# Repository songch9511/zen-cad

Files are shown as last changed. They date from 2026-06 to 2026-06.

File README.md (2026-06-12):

# Zen CAD

기계 설계 에이전트를 위한 assembly-first CAD contract runtime입니다.






Zen CAD는 Codex 같은 범용 에이전트가 자연어 기계 설계 요청을 더 검사 가능한 CAD 작업으로 바꾸도록 돕습니다. 핵심 규칙은 단순합니다. **형상을 예쁘게 만들기 전에 기계적 의도를 먼저 잠급니다.**

워크플로는 CAD-native spec에서 시작합니다. 그 다음 frame, datum, axis, bore, shaft, bolt pattern, pitch reference, clearance, motion relationship, source evidence를 layout, generation, review, handoff artifact 전체에 걸쳐 보존합니다.

## 현재 버전

- 제품/plugin 버전: `1.1.0`
- contract schema 버전: `0.8.0`
- 기본 local generation target: `build123d`
- review target: generated STEP + 선택적 repo-local viewer link/snapshot
- evidence 우선순위: 측정 가능한 geometry check 먼저, visual review는 그 다음, prose caveat는 마지막

## 하는 일

- 자연어 기계 설계 요청을 CAD-native spec으로 변환합니다.
- layout, interface, inspection, proceed review, handoff용 machine-readable contract package를 만듭니다.
- local dependency가 있으면 first-pass build123d STEP artifact를 생성합니다.
- hole, bore, repeated hole pattern, chamfer, 지원되는 fillet approximation, simplified gear teeth 같은 feature intent를 보존합니다.
- 명시적 evidence가 있으면 source-locked STEP/STP 부품을 generated build123d source에 import합니다.
- `interface_frame`과 `replacement_plan` contract로 source/detail CAD가 proxy를 치환해도 locked facts가 움직이지 않게 합니다.
- `detail_shape_plan`으로 custom part가 사용자 shape intent를 따르면서 protected interface zone을 보존하게 합니다.
- repo-local viewer review link와 선택적 PNG snapshot을 package합니다.
- floating body, interference, clearance, fastening, alignment, mesh/contact, implausible support path를 visual/engineering review에서 점검하도록 안내합니다.

## 하지 않는 일

- CAD kernel, CAE solver, manufacturing review, certification process를 대체하지 않습니다.
- supplier SKU 정확성, 재고, rating, certification, compliance claim을 보장하지 않습니다.
- 광범위한 catalog crawling을 기본 동작으로 하지 않습니다.
- screenshot이나 viewer link만으로 완료를 증명하지 않습니다.
- 특정 subagent runtime을 강제하지 않습니다. subagent가 있으면 dispatch plan을 쓰고, 없으면 lead agent가 같은 review role을 순차 실행합니다.

## Workflow

1. locked parameter, frame, interface, inspection target을 포함한 CAD-native spec을 작성합니다.
2. kernel-neutral layout proxy를 생성하고 locked facts가 보존됐는지 검사합니다.
3. build123d source를 export하고 source-level carry-through를 검사합니다.
4. `build123d`가 가능하면 STEP artifact를 생성합니다.
5. standard/catalog proxy는 interface frame mapping과 inspection이 가능할 때 source-locked STEP/STP로 치환합니다.
6. source component가 아닌 custom part는 locked facts와 user shape intent를 기반으로 constrained detail CAD를 생성합니다.
7. inspection report, generated artifact, 선택적 viewer evidence를 proceed gate로 package합니다.
8. visual/mechanical review를 수행하고 가장 작은 source-level 원인을 수정한 뒤 재생성합니다.
9. 사용자 approval 이후 downstream detail handoff를 생성합니다.

## Codex 사용법

local plugin bundle은 [`plugins/zen-cad`](plugins/zen-cad)에 있습니다. 폴더를 project로 연결하는 것만으로는 slash skill이 등록되지 않습니다. `.codex-plugin/marketplace.json`에서 local `zen-cad` plugin을 설치한 뒤 새 chat을 시작하세요.

주요 entrypoint:

- `/cad-spec`
- `/assembly-layout`
- `/interface-signatures`
- `/cad-handoff`
- `/cad-replacement`
- `/constrained-detail-cad`

plain prompt로도 사용할 수 있습니다.

```text
Use skills/cad-spec/SKILL.md to create a CAD-native spec for:
Create a flat planetary gear assembly with separate sun, planet, ring, carrier, and pin bodies. Use simplified trapezoidal teeth and place three planets around the sun on a 42 mm radius circle.
```

generation과 review까지 이어갈 때는 다음 지시가 유용합니다.

```text
Create the CAD-native spec, generate the first-pass STEP if the local harness supports it, inspect the result visually and mechanically, repair source-level issues, and package the proceed gate. Use specialist subagents if available; otherwise run the same review roles sequentially.
```

## CoBrA 사용법

CoBrA workspace skill로 설치하려면 installer를 실행합니다.

```bash
python3 tools/install_cobra.py --with-cad-deps
```

설치 후 새 CoBrA chat을 시작하거나 skill picker를 새로고침한 뒤 `/zen-cad` 또는 `/cad-spec`로 시작합니다.

```text
/zen-cad create a NEMA17 mount plate
/cad-spec create a GT2 belt driven linear slide
```

CAD 의존성 없이 spec/handoff만 사용하려면 `--with-cad-deps`를 빼고 실행합니다. 자세한 옵션은 [`docs/cobra_usage.md`](docs/cobra_usage.md)를 보세요.

## Command Flow

전체 local build123d pipeline:

```bash
python3 tools/run_contract_pipeline.py --package <contract-package> --out <run-dir> --target-harness build123d
```

`http://localhost:5173`용 repo-local viewer link 생성:

```bash
(cd viewer && npm run dev:local)
python3 tools/run_contract_pipeline.py --package <contract-package> --out <run-dir> --target-harness build123d --viewer-base-url http://localhost:5173
```

review evidence용 viewer snapshot capture:

```bash
python3 tools/run_contract_pipeline.py --package <contract-package> --out <run-dir> --target-harness build123d --viewer-base-url http://localhost:5173 --capture-viewer-snapshot
```

proceed gate 승인 후 detail handoff 생성:

```bash
python3 tools/approve_proceed_gate.py --proceed-gate <run-dir>/proceed_gate.json --out <approval.json>
python3 tools/run_contract_pipeline.py --package <contract-package> --out <detail-run-dir> --target-harness text-to-cad --approval <approval.json>
```

step.parts source download 및 source-lock 생성:

```bash
python3 tools/download_step_part.py --id <step-parts-id> --download --out-dir <contract-package>/sourced_parts/step_parts --package <contract-package> --part-id <part-id> --source-lock-out <contract-package>/<part-id>_source_lock.json
```

## 1.1 핵심: Proxy 이후

1.1.0에서 layout proxy는 단순한 rough visual placeholder가 아닙니다. proxy는 source/detail CAD를 끼워 넣기 위한 **정밀 interface scaffold**입니다.

### Source/Detail Replacement

`/cad-replacement`는 proxy part를 source-locked STEP/STP, user-provided detail CAD, generated detail candidate로 치환할 때 사용합니다.

핵심 contract:

- proxy `interface_frame`
- source/detail `interface_frame`
- `replacement_plan`
- frame transform: `world_source = world_proxy_frame * inverse(source_frame)`
- post-replacement locked-fact inspection

source geometry가 import됐다는 사실만으로는 충분하지 않습니다. 치환 후 axis, plane, bolt pattern, clearance, relationship이 tolerance 안에 들어왔는지 측정해야 합니다.

### Constrained Detail CAD

`/constrained-detail-cad`는 bracket, plate, cover, housing, adapter 같은 custom part를 만들 때 사용합니다.

custom detail generation은 세 영역을 분리합니다.

- protected interface zone: bore, shaft, bearing seat, mounting plane, bolt pattern, clearance envelope, motion sweep
- functional structure zone: rib, boss, wall, support path, shell
- freeform/style zone: outer silhouette, pocket, cosmetic relief, edge treatment

사용자 shape intent는 중요하지만 soft constraint입니다. locked facts, protected zone, clearance rule은 hard constraint입니다.

## Native Benchmarks

curated benchmark package는 [`benchmarks/`](benchmarks)에 있습니다.

- rectangular calibration block
- circular flange
- simplified planetary gear stage

각 benchmark는 through-hole, bore, bolt circle, chamfer, edge-round approximation, separate bodies, repeated gear-like teeth처럼 Zen CAD가 보존해야 하는 feature를 작게 검증합니다.

## Visual Review And Repair

Zen CAD의 visual review는 simulation이 아닙니다. 목표는 generated CAD를 보고 기계적 문제를 이름 붙인 뒤, 이를 측정 가능한 contract check로 바꾸고, source를 고친 뒤, 다시 생성하는 것입니다.

review에서 확인할 항목:

- floating 또는 unsupported body
- unintended intersection
- insufficient clearance
- missing fastener engagement
- shaft, bore, bearing, pulley misalignment
- belt, gear, contact-plane mismatch
- weak 또는 implausible load path

viewer screenshot은 review artifact로 유용하지만 완료 evidence는 아닙니다. 완료 판단은 geometry report, locked facts, inspection check, user approval에 의존합니다.

## Repository Map

- [`skills/`](skills): agent-facing workflow
- [`schemas/`](schemas): machine-readable contract surface
- [`registry/interfaces/`](registry/interfaces): layout-ready interface facts
- [`tools/run_contract_pipeline.py`](tools/run_contract_pipeline.py): one-command pipeline runner
- [`tools/generate_cad_artifact.py`](tools/generate_cad_artifact.py): build123d STEP generation 및 inspection
- [`tools/download_step_part.py`](tools/download_step_part.py): step.parts download 및 checksum-backed source-lock evidence
- [`tools/package_viewer_link.py`](tools/package_viewer_link.py): repo-local viewer link packaging
- [`tools/capture_viewer_snapshot.py`](tools/capture_viewer_snapshot.py): 선택적 viewer PNG capture
- [`schemas/interface_frame.schema.json`](schemas/interface_frame.schema.json): proxy/source/detail frame anchor
- [`schemas/replacement_plan.schema.json`](schemas/replacement_plan.schema.json): source/detail replacement transform 및 inspection contract
- [`schemas/detail_shape_plan.schema.json`](schemas/detail_shape_plan.schema.json): locked facts와 shape intent 기반 custom detail CAD plan

## Development Checks

```bash
python3 tools/validate_contract.py
python3 -m unittest discover -s tests
python3 -m py_compile tools/*.py tests/*.py
```

temporary project run은 `work/` 같은 ignored run directory에 둡니다. curated benchmark contract는 [`benchmarks/`](benchmarks)에 둡니다.

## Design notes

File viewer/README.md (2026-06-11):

# Zen CAD Viewer

Repo-local CAD review viewer for Zen CAD generated artifacts.

This starts from the existing Vite/React/Three viewer and moves it under the
Zen CAD repository so the contract pipeline can package review links without
depending on a separate checkout.

## Current Slice

- STEP/STP, STL, OBJ, glTF, and GLB loading.
- In-browser STEP tessellation through OpenCascade WASM.
- Render modes, camera presets, fit/reset controls, scene tree, part visibility,
  part coloring, simple transforms, animation playback, and overlap review.
- Query-string model loading through `?model=/zen-cad-artifacts/<file.step>`.
- Pipeline drop directory at `public/zen-cad-artifacts/`.

## Direction

The target architecture follows the workbench split used by
`earthtojake/text-to-cad/viewer`:

- `viewer/` owns React UI, workbench state, file navigation, panels, and review
  interactions.
- A future viewer runtime package should own CAD parsing, scene construction,
  STEP sidecars, selector data, and render helpers without React dependencies.
- Zen CAD tools should hand the viewer generated STEP, layout scene JSON,
  source manifests, proceed gates, and review bundles from inside this repo.

## Commands

```bash
npm install
npm run dev:local
npm run build
```

The default local URL is `http://localhost:5173`.

## Pipeline Use

For an auto-load review link, pass this viewer's public directory:

```bash
python3 ../tools/run_contract_pipeline.py \
  --package <contract-package> \
  --out <run-dir> \
  --target-harness build123d \
  --viewer-base-url http://localhost:5173 \
  --viewer-public-dir "$(pwd)/public"
```

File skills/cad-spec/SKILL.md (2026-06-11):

---
name: cad-spec
description: Write CAD-native mechanical specs from natural-language design requests and orchestrate CAD work through specialist subagents when available. Use for assembly-first layout specs, parameter contracts, artifact targets, inspection plans, interface definitions, coordinate frames, datums, motion/drivetrain relationships, proxy fidelity boundaries, interface-frame contracts, source/detail replacement, constrained detail shape plans, visual inspection and repair loops, proceed gates, subagent delegation, and downstream CAD handoffs.
version: 1.1.0
---

# CAD Spec

## Purpose

Use this skill before asking a CAD-generation agent or CAD toolchain to create geometry. It converts a user's natural-language mechanical request into a CAD-native spec that a downstream harness can model, inspect, repair, and revise.

This skill owns the spec and assembly contract. It also defines the parameter contract, artifact targets, inspection plan, repair rules, and downstream handoff. It may coordinate CAD work by delegating bounded specialist subtasks when the harness supports subagents. It should not perform catalog crawling, manufacturing certification, or broad report packaging.

Core rule: **spec the assembly contract before generating CAD.** For assemblies, prioritize coordinate frames, datums, axes, mating primitives, center distances, clearances, transmission relationships, and locked layout facts over surface fidelity.

## Use This Skill When

Use `cad-spec` when the user asks for:

- a mechanical part or assembly from prose;
- an assembly with motors, bearings, belts, pulleys, gears, rails, shafts, fasteners, or moving interfaces;
- a first-pass layout proxy whose coupling structure must be correct;
- a proceed/review checkpoint before detail modeling;
- a parameterized CAD brief with named dimensions, derived relationships, and validation targets;
- artifact targets for source, STEP/STP, snapshots, viewer links, or secondary exports;
- specialist subagents for layout, interfaces, motion, CAD generation, visual inspection, engineering review, or repair;
- local build123d STEP generation or a downstream handoff to `$cad`, text-to-cad, CadQuery, FreeCAD, or another CAD generator.
- native feature-aware generation for holes, bores, bolt-circle patterns, repeated hole patterns, rectangular top chamfers, simplified gear teeth, or supported cylinder edge-round approximations.
- replacement of layout proxies with source-locked STEP/STP or detail CAD while preserving locked facts;
- custom detail CAD generation from locked interface frames plus user shape intent.

Do not use this skill for CAM, G-code, visual concept art, FEA, procurement-ready sourcing, or manufacturing certification unless the user first needs a CAD-native spec for those downstream tasks.

## Default Assumptions

Use these defaults unless the user specifies otherwise:

- Units: millimeters.
- Angles: degrees in prose, radians only when a downstream API requires them.
- Root frame: stable mounting/base component when known; otherwise the assembly footprint center.
- Base plane: XY.
- Up axis: +Z.
- First artifact target: low-detail `layout_proxy`.
- Surface fidelity: intentionally low for layout; boxes, cylinders, envelopes, simplified teeth, and coarse sweeps are acceptable.
- Interface fidelity: high from the first pass; axes, bores, mounting faces, bolt patterns, pitch references, and clearances must be explicit.
- Primary artifact intent: STEP/STP when the active CAD generator supports it.
- Parameter policy: named parameters with units, source, locked status, driven features, and validation targets.
- Replacement policy: proxies are interface scaffolds; source/detail CAD may replace them only through frame mapping and post-replacement inspection.
- Custom detail policy: user shape intent is soft; locked interface frames, protected zones, and clearance rules are hard.

Ask one focused question only when missing information makes the layout impossible, fit-critical, safety-critical, or compliance-bound. Otherwise proceed with named assumptions and mark them as not locked.

## Required Workflow

1. Classify the request as single part, static assembly, moving assembly, modification, inspection brief, or downstream handoff.
2. Load only the relevant references listed below.
3. Write a concise CAD-native Markdown spec. Do not ask the user to provide JSON/YAML.
4. Define the coordinate system, root frame, part-local frames, and dominant datums.
5. Define named parameters, units, selected values, locked/assumed/derived status, driven features, and validation targets.
6. Define artifact targets: maturity, CAD source intent, primary CAD artifact, secondary outputs, and review evidence.
7. Define the assembly graph: parts, roles, fixed/moving relationships, and repeated component families.
8. Define interface primitives: planes, cylinders, bores, shafts, bolt circles, pitch circles, rails, slots, belt planes, gear mesh references, cable/keep-out envelopes, and fastener axes.
9. Define motion or drivetrain relationships when present.
10. Define proxy fidelity boundaries: what may be simplified and what must remain dimensionally meaningful.
11. Define locked layout facts and a proceed gate so the user can approve positioning before detail modeling.
12. Define an inspection plan and repair loop for generated CAD.
13. If CAD generation or review is requested, write a Subagent Dispatch Plan before generating geometry, then spawn specialist subagents where the harness supports delegation.
14. Define a visual inspection and engineering repair plan for generated CAD: required views, issue taxonomy, measurable checks, and repair stop conditions.
15. If the active target is build123d and generation is requested, run the build123d source/export/inspection path before proceed review.
16. If a viewer is available, capture review evidence and inspect it for fastening, clearance, floating body, interference, mesh/alignment, and engineering plausibility issues.
17. If native build123d generation needs detail features, encode them in `cad_spec.extensions.cad_feature_plan` instead of burying them in prose.
18. If sourced/detail replacement is requested, hand off to `cad-replacement` with proxy frames, source frames, source-lock evidence, and required post-replacement checks.
19. If user-shaped custom detail CAD is requested, hand off to `constrained-detail-cad` with locked interfaces, protected zones, shape intent, and required inspection checks.
20. Write a downstream CAD handoff targeted to the active harness when external generation or detail upgrade is needed.

## Machine-Readable Contracts

Do not ask users to write JSON or YAML. When a harness needs machine-readable artifacts, derive them from the Markdown spec using the repo-level schemas:

- `schemas/cad_spec.schema.json`
- `schemas/layout_contract.schema.json`
- `schemas/interface_signature.schema.json`
- `schemas/inspection_report.schema.json`
- `schemas/handoff_packet.schema.json`
- `schemas/layout_proxy_scene.schema.json`
- `schemas/cad_source_manifest.schema.json`
- `schemas/proceed_gate_package.schema.json`
- `schemas/proceed_approval.schema.json`
- `schemas/pipeline_run.schema.json`
- `schemas/source_lock_evidence.schema.json`
- `schemas/interface_frame.schema.json`
- `schemas/replacement_plan.schema.json`
- `schemas/detail_shape_plan.schema.json`

Use `source_lock_evidence` only for final-stage standard/catalog part sourcing. It records explicit step.parts, manufacturer, datasheet, project-file, or user-provided evidence without treating layout interface signatures as final proof.

Use `registry/interfaces/index.json` for built-in layout-ready interface signatures before attempting external catalog research.

## Specialist Subagents

Use subagents for complex assemblies, moving mechanisms, generated CAD review, visual inspection, engineering plausibility checks, or any task where independent layout/interface/motion/review work can run in parallel. Keep the lead agent responsible for the final spec and for reconciling conflicts.

When the user asks for CAD generation, generated artifact review, or repair, the lead must create a **Subagent Dispatch Plan** before generating or revising geometry. The plan must name each bounded role, input artifacts, expected output, and stop condition. If the active harness exposes subagents, spawn the listed roles. If subagents are unavailable, explicitly state `Subagent status: unavailable; using sequential fallback roles` and run the same roles sequentially before finalizing.

Default specialist roles:

- `layout-specialist`: root frame, part-local frames, assembly graph, contacts, connections, locked layout facts.
- `interface-specialist`: standard component interface signatures, bolt patterns, bores, shafts, rails, belts, envelopes, and must-confirm facts.
- `parameter-specialist`: named parameters, defaults, derived values, allowed ranges, driven features, and validation targets.
- `motion-specialist`: joints, travel, transmission ratios, gear/belt/screw relationships, motion limits, and keep-outs.
- `cad-generator`: low-detail layout proxy or detail CAD from the approved spec, preserving locked facts.
- `replacement-specialist`: source/detail replacement through interface-frame mapping, transform planning, and post-replacement locked-fact inspection.
- `detail-shape-specialist`: custom detail shape planning with protected zones, user shape intent, manufacturing assumptions, and inspection gates.
- `cad-reviewer`: compare generated CAD against parameters, locked facts, inspection plan, proceed gate, allowed simplifications, and stated assumptions.
- `visual-reviewer`: inspect viewer snapshots/multi-view evidence for floating bodies, unintended intersections, missing fasteners, insufficient clearances, misaligned axes/planes, and visibly implausible load paths.
- `engineering-reviewer`: convert visual concerns into measurable checks for fastening engagement, shaft/bore fit, bearing support, belt or gear mesh, wall thickness, support, clearance, and assembly feasibility.

Spawn only bounded tasks. Give each subagent the minimum relevant spec sections, expected output, and stop conditions. Do not ask subagents to browse broadly for parts, invent final ratings, or rewrite the whole spec. If subagents are unavailable, perform the same roles as sequential local passes.

## Required Spec Sections

Every useful spec should include:

```text
# CAD Spec: <short name>

## Intent
## Coordinate System
## Parameter Contract
## Artifact Targets
## Parts And Roles
## Assembly Graph
## Interface Primitives
## Interface Frame Contract
## Motion And Drivetrain
## Proxy Fidelity Policy
## Replacement And Detail Shape Plan
## Locked Layout Facts
## Inspection Plan
## Repair Loop
## Visual Inspection And Engineering Review
## Assumptions And Open Questions
## Proceed Gate
## Downstream CAD Handoff
```

Omit a section only when it is truly out of scope, and say why.

## Non-Negotiables

- Do not bury positioning facts inside prose-only descriptions. Name the datum, axis, frame, or interface primitive.
- Do not let surface detail outrank assembly correctness in the first pass.
- Do not crawl catalogs before writing the layout spec.
- Do not crawl catalogs before checking the built-in interface registry for layout-ready facts.
- Do not claim a proxy is final geometry.
- Do not hand off CAD generation without named parameters and validation targets for critical dimensions.
- Do not treat screenshots or viewer links as substitutes for geometry facts, measurements, frames, or mate checks.
- Do not close proceed review on generated assemblies until floating bodies, unintended interference, fastening/clearance concerns, and visible mesh/alignment concerns are either checked, repaired, or recorded as skipped with a concrete reason.
- Do not allow detail modeling to change locked layout facts without returning to the proceed gate.
- Do not replace a proxy with source/detail CAD unless proxy frames and source/detail frames are mapped and inspected.
- Do not let user-requested shape style modify protected interface zones, clearances, mounting datums, bores, shafts, or bolt patterns.
- Do not present CAD validation, viewer screenshots, or generated geometry as engineering certification.
- Do not claim selector-based topology fillets/chamfers unless the active build123d/OCP runtime actually ran those operations; use the inspection report limitations when approximations are used.
- Do not embed repository paths or harness workspace paths in the core spec unless the downstream handoff specifically requires them.

## Progressive References

Load these files only when the trigger applies:

- `references/natural-language-to-cad-spec.md` — converting prose requests into a CAD-native spec.
- `references/parameter-contract.md` — named parameters, units, locked/assumed/derived status, and validation targets.
- `references/export-targets.md` — layout/detail/final maturity, source intent, primary artifacts, secondary exports, and review evidence.
- `references/assembly-positioning.md` — root frames, part-local datums, mating primitives, center distances, and locked facts.
- `references/interface-primitives.md` — planes, cylinders, bores, shafts, bolt patterns, pitch references, rails, slots, and fastener axes.
- `references/motion-and-drivetrain.md` — belts, pulleys, gears, screws, sliders, rotary axes, limits, and transmission relationships.
- `references/proxy-fidelity.md` — what layout proxies may simplify and what they must preserve.
- `references/inspection-and-repair.md` — generated CAD checks, snapshot/viewer expectations, failure classes, and repair loops.
- `references/visual-inspection-and-repair.md` — multi-view visual review, issue taxonomy, engineering plausibility checks, and visual-to-measurable repair loops.
- `references/proceed-gate.md` — user approval, locked facts, and detail-stage drift rules.
- `references/specialist-subagents.md` — when and how to delegate CAD work to specialist subagents.
- `references/downstream-cad-handoff.md` — active harness, `$cad`, text-to-cad, and generic CAD generator handoffs.

## Final Response

Return the spec itself or the path where you wrote it, plus a short handoff summary:

```text
Spec status: ready for layout CAD | needs one clarification | blocked
Layout risk: <main positioning or interface risk>
Proceed gate: <what the user must approve before detail modeling>
Downstream target: <harness/toolchain if known>
```

If the user asked you to continue into CAD generation and the appropriate CAD skill/tool is available, hand off the spec after writing it. Otherwise stop at the spec and state the next command or skill target plainly.

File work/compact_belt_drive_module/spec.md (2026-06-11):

# CAD Spec: Compact Belt-Drive Module

## Intent

Create a compact layout-proxy assembly for a GT2 belt-drive module mounted on a flat base plate. The module uses a NEMA 17 stepper motor driving a 20T GT2 pulley on the motor shaft, a parallel 8 mm output shaft supported by a 608 bearing, and a matching 20T GT2 pulley on the output shaft. The first pass prioritizes shaft axes, pulley pitch references, bearing bore alignment, belt centerline alignment, mounting patterns, and source-lock traceability over surface fidelity.

Classification: moving drivetrain assembly.

## Coordinate System

- Units: millimeters.
- Root frame: `base_plate_frame`.
- Base plane: XY.
- Up axis: +Z.
- Origin: center of the base plate lower face.
- +X: motor-to-output shaft direction.
- +Y: lateral direction across the belt spans in the base plane.
- +Z: shaft axis direction, motor shaft direction, and pulley/belt width direction.

Part-local frames:

| Part | Local Frame |
| --- | --- |
| `base_plate` | Origin at base plate lower-face center; XY footprint, +Z through plate thickness. |
| `nema17_motor` | Origin on motor shaft centerline at front mounting face; shaft axis +Z; body extends below plate in -Z. |
| `motor_pulley_20t_5mm` | Origin at pulley pitch-plane center on motor shaft axis; bore axis +Z; pitch plane XY. |
| `output_shaft_8mm` | Origin at output shaft center where it crosses the belt mid-plane; shaft axis +Z. |
| `output_pulley_20t_8mm` | Origin at pulley pitch-plane center on output shaft axis; bore axis +Z; pitch plane XY. |
| `bearing_608` | Origin at bearing bore center; bearing axis +Z; outer race seat concentric with support pocket. |
| `bearing_support_block` | Origin at output shaft axis projected to top face of base plate; pocket axis +Z. |
| `gt2_belt_loop` | Origin at midpoint between pulley axes on `belt_mid_plane_z`; belt mid-plane is XY. |
| `motor_fasteners_m3` | Four axes normal to motor mounting face, on the NEMA 17 31 mm square pattern. |
| `bearing_support_fasteners_m3` | Four axes normal to the base plate around the bearing support block. |

## Parameter Contract

| Name | Units | Value | Status | Source | Drives | Validation |
| --- | ---: | ---: | --- | --- | --- | --- |
| `base_plate_length` | mm | 125 | assumed | layout assumption | `base_plate` envelope | Bounding box X dimension is 125 mm. |
| `base_plate_width` | mm | 75 | assumed | layout assumption | `base_plate` envelope | Bounding box Y dimension is 75 mm. |
| `base_plate_thickness` | mm | 6 | assumed | layout assumption | `base_plate` envelope, motor shaft clearance | Plate thickness is 6 mm and does not consume the whole motor shaft length. |
| `motor_axis_x` | mm | -35 | locked | layout assumption | `nema17_motor.shaft_axis` | Motor shaft axis world X is -35 mm. |
| `output_axis_x` | mm | 35 | locked | derived constraint | `output_shaft_8mm.shaft_axis`, `bearing_608.bearing_axis` | Output shaft/bearing axis world X is 35 mm. |
| `axis_y` | mm | 0 | locked | derived constraint | all shaft axes | Both shaft axes share Y = 0. |
| `pulley_center_distance` | mm | 70 | locked | layout assumption | belt spans, base footprint | Distance between motor and output shaft axes is 70 mm. |
| `shaft_axis_direction` | dimensionless | +Z | locked | layout assumption | motor, output shaft, bearing, pulleys | All shaft/bore axes are parallel to +Z. |
| `belt_mid_plane_z` | mm | 13.5 | locked | layout assumption | pulley pitch planes, belt centerline | Both pulley pitch planes and belt centerline share Z = 13.5 mm. |
| `motor_mount_pattern_spacing` | mm | 31 | locked | project registry | NEMA 17 mounting holes | Four motor fastener axes form a 31 mm square pattern. |
| `motor_face_size` | mm | 42.3 | assumed | project registry | motor body proxy | Motor face envelope is 42.3 mm square nominal. |
| `motor_shaft_diameter` | mm | 5 | assumed | source/product candidate | motor pulley bore | Motor pulley bore candidate is 5 mm and must be confirmed for the final motor. |
| `gt2_pitch` | mm | 2 | locked | project registry | belt and pulley pitch references | Belt pitch is 2 mm. |
| `gt2_belt_width` | mm | 6 | locked | project registry | pulley width, belt envelope | Belt width envelope is 6 mm. |
| `pulley_tooth_count` | count | 20 | assumed | source/product candidate | both pulleys | Both pulleys are 20T for 1:1 ratio. |
| `pulley_pitch_diameter` | mm | 12.732 | derived | derived constraint | pitch circles | `tooth_count * gt2_pitch / pi`, tolerance +/-0.05 mm in detail CAD. |
| `belt_length_nominal` | mm | 180 | derived | derived constraint | closed-loop belt candidate | Equal 20T pulleys at 70 mm center distance imply about 180 mm pitch length. |
| `bearing_bore_diameter` | mm | 8 | locked | project registry | bearing bore, shaft fit | 608 bore and shaft nominal diameter are 8 mm. |
| `bearing_outer_diameter` | mm | 22 | locked | project registry | bearing support pocket | Bearing seat OD is 22 mm nominal. |
| `bearing_width` | mm | 7 | locked | project registry | bearing support pocket height | Bearing axial width is 7 mm. |
| `output_shaft_diameter` | mm | 8 | locked | project registry | shaft, output pulley bore, bearing bore | Shaft, bearing bore, and output pulley bore are coaxial at 8 mm nominal. |
| `output_shaft_length` | mm | 45 | assumed | layout assumption | output shaft proxy | Shaft extends through bearing and output pulley without changing locked axes. |
| `m3_clearance_diameter` | mm | 3.4 | locked | project registry | motor/support fastener holes | M3 clearance holes use 3.4 mm layout diameter. |
| `bearing_seat_radial_clearance` | mm | 0.05 | assumed | layout assumption | bearing pocket | Seat is represented as OD + 0.10 mm diameter in proxy; fit class must be selected before final. |

## Artifact Targets

- Target maturity: `layout_proxy`.
- CAD source intent: build123d adapter generated by Zen CAD runtime.
- Primary review artifact: kernel-neutral `layout_proxy.scene.json`.
- Secondary artifacts: generated build123d source adapter, CAD source manifest, inspection reports, proceed gate package, review bundle.
- Source-of-truth rule: this Markdown spec plus `cad_spec.json` and `layout_contract.json` define the contract. Generated files are derived review aids.

## Parts And Roles

| Part ID | Role | Interface Signatures | Source-Lock Intent |
| --- | --- | --- | --- |
| `base_plate` | structure | none | custom generated plate, not a catalog part. |
| `nema17_motor` | driver | `motor.nema_17.layout` | source-lock to a concrete NEMA 17 motor candidate before final. |
| `motor_pulley_20t_5mm` | driven | `belt.gt2_6mm.layout` | source-lock to a 20T GT2, 5 mm bore, 6 mm belt pulley. |
| `output_shaft_8mm` | driven | `shaft_bore.8mm.layout` | source-lock to an 8 mm shaft/rod candidate. |
| `output_pulley_20t_8mm` | driven | `belt.gt2_6mm.layout`, `shaft_bore.8mm.layout` | source-lock to a 20T GT2, 8 mm bore, 6 mm belt pulley. |
| `bearing_608` | guide | `bearing.608.layout` | source-lock to 608 or 608ZZ/2RS bearing candidate. |
| `bearing_support_block` | structure | none | generated custom block with bearing seat. |
| `gt2_belt_loop` | driven | `belt.gt2_6mm.layout` | optional source-lock to 180 mm closed-loop GT2 belt before final. |
| `motor_fasteners_m3` | fastener | `fastener.m3_clearance.layout` | source-lock to M3 socket head screws after stack height is confirmed. |
| `bearing_support_fasteners_m3` | fastener | `fastener.m3_clearance.layout` | source-lock to M3 socket head screws after stack height is confirmed. |

## Assembly Graph

- `base_plate` is fixed and defines the root frame.
- `nema17_motor` is fixed to `base_plate` by `motor_fasteners_m3`; its front mounting face is flush to the underside of the base plate.
- `motor_pulley_20t_5mm` is fixed coaxially to the NEMA 17 motor shaft.
- `bearing_support_block` is fixed to the top of `base_plate`.
- `bearing_608` is seated in `bearing_support_block`; the bearing bore axis is +Z.
- `output_shaft_8mm` rotates in `bearing_608` and is coaxial with the bearing bore.
- `output_pulley_20t_8mm` is fixed coaxially to `output_shaft_8mm`.
- `gt2_belt_loop` couples `motor_pulley_20t_5mm` to `output_pulley_20t_8mm` through pitch contact in the shared belt mid-plane.

## Interface Primitives

- `base_plate_top_plane`: datum plane at Z = 6 mm.
- `base_plate_bottom_plane`: datum plane at Z = 0 mm.
- `motor_mount_face`: NEMA 17 front face flush to `base_plate_bottom_plane`; shaft axis normal to face.
- `motor_shaft_axis`: axis through X = -35 mm, Y = 0 mm, direction +Z.
- `output_shaft_axis`: axis through X = 35 mm, Y = 0 mm, direction +Z.
- `bearing_axis`: coincident with `output_shaft_axis`.
- `bearing_outer_race_seat`: cylinder OD 22.10 mm assumed proxy seat, axis `bearing_axis`, width 7 mm minimum.
- `motor_mount_pattern`: four M3 clearance axes on 31 mm square, centered on `motor_shaft_axis`.
- `support_mount_pattern`: four M3 clearance axes around the output support block, centered on `output_shaft_axis`; exact spacing assumed 32 mm x 26 mm.
- `motor_pulley_pitch_circle`: 20T GT2 pitch circle, diameter 12.732 mm, centered on `motor_shaft_axis` at `belt_mid_plane_z`.
- `output_pulley_pitch_circle`: 20T GT2 pitch circle, diameter 12.732 mm, centered on `output_shaft_axis` at `belt_mid_plane_z`.
- `belt_mid_plane`: XY plane at Z = 13.5 mm.
- `belt_centerline`: GT2 closed loop tangent to both pulley pitch circles in `belt_mid_plane`.
- `belt_keep_out`: 6 mm belt width plus 2 mm lateral clearance; no support block or fastener head may enter this envelope.

## Motion And Drivetrain

- Joint `motor_rotor_joint`: revolute about `motor_shaft_axis`.
- Joint `motor_pulley_joint`: fixed to motor shaft; pulley rotation follows motor 1:1.
- Joint `output_shaft_bearing_joint`: revolute about `bearing_axis`/`output_shaft_axis`.
- Belt relationship: GT2 belt pitch contact between equal 20T pulleys, pitch 2 mm, belt width 6 mm.
- Ratio: 1:1 because both pulleys are 20T.
- Nominal belt length: approximately 180 mm pitch length for equal 20T pulleys at 70 mm center distance. Final belt selection must confirm tooth count, belt length, and tensioning method.
- Tensioning strategy: no separate tensioner in the layout proxy. Detail CAD may add motor mounting slots or a sliding support only if the approved axes and belt mid-plane remain preserved, or the design returns to the proceed gate.

## Proxy Fidelity Policy

The layout proxy may simplify:

- NEMA 17 body shape, rear cap, connector, cable exit, and exact length.
- Pulley tooth profiles, flanges, set screws, and hub details.
- Bearing balls, cage, seals/shields, chamfers, and fit tolerances.
- Shaft end details, flats, retaining rings, threads, and surface finish.
- Fastener head recesses and thread geometry.
- Base plate edge treatment, pocket fillets, labels, and cosmetic chamfers.

The layout proxy must preserve:

- Root frame and base plate datum planes.
- Motor shaft axis, output shaft axis, bearing axis, and their +Z orientation.
- 70 mm pulley center distance.
- NEMA 17 31 mm square mounting pattern.
- 608 bearing 8 mm bore, 22 mm OD, and 7 mm width.
- 8 mm output shaft nominal diameter.
- GT2 pitch 2 mm, 6 mm belt width, 20T pitch references, and shared belt mid-plane.
- M3 clearance hole layout diameter.
- Belt keep-out envelope around both pitch spans.

## Locked Layout Facts

1. `root_frame_locked`: `base_plate_frame` uses XY base plane, +Z up, origin at base lower-face center.
2. `shaft_axes_parallel_z_locked`: motor shaft axis, output shaft axis, and bearing axis are parallel to +Z.
3. `pulley_center_distance_locked`: motor and output shaft axes are 70 mm apart along +X.
4. `motor_axis_position_locked`: motor shaft axis is X = -35 mm, Y = 0 mm.
5. `output_axis_position_locked`: output shaft/bearing axis is X = 35 mm, Y = 0 mm.
6. `belt_midplane_locked`: both pulley pitch planes and the belt centerline are in the XY plane at Z = 13.5 mm.
7. `motor_mount_pattern_locked`: NEMA 17 motor pattern is four M3 clearance axes on a 31 mm square centered on the motor shaft axis.
8. `bearing_interface_locked`: 608 bearing interface is 8 mm bore, 22 mm OD, 7 mm width, coaxial with output shaft.
9. `output_shaft_interface_locked`: output shaft nominal diameter is 8 mm and coaxial with the bearing bore and output pulley.
10. `gt2_interface_locked`: GT2 pitch is 2 mm, belt width is 6 mm, pulley tooth count is 20T at both shafts, and ratio is 1:1.
11. `fastener_clearance_locked`: M3 layout clearance diameter is 3.4 mm for motor and support fastener axes.

## Inspection Plan

- Check the generated scene has all required top-level parts and labels.
- Check `base_plate_frame` root axes match XY base plane and +Z up.
- Check motor shaft, output shaft, and bearing axes are present and direction +Z.
- Check motor-output axis distance is 70 mm.
- Check both pulley pitch references share `belt_mid_plane_z`.
- Check `bearing_608` bore, output shaft, and output pulley are coaxial.
- Check NEMA 17 mounting pattern is centered on the motor shaft axis and uses 31 mm square spacing.
- Check 608 bearing dimensions are 8 x 22 x 7 mm.
- Check GT2 belt pitch, width, pitch circles, and belt keep-out are represented.
- Check source-lock evidence exists for the standard motor, pulleys, bearing, shaft, and fasteners before final packaging.

## Repair Loop

If a generated artifact fails inspection:

1. Classify the failure as missing part, wrong frame, wrong axis, wrong distance, missing interface primitive, source-lock gap, or unsupported downstream export.
2. Change the smallest responsible source contract, parameter, datum, relationship, or handoff instruction.
3. Regenerate the affected layout proxy, source adapter, inspection report, and proceed package.
4. Rerun the failed check and dependent alignment checks.
5. Stop and return to the proceed gate if a repair would change a locked axis, center distance, belt mid-plane, mounting pattern, bearing interface, or drivetrain ratio.

## Assumptions And Open Questions

- The module uses vertical, parallel shaft axes with the motor mounted below the base plate and pulleys above the plate. This is a compact plate-mounted architecture; approve or revise at the proceed gate.
- The selected 70 mm center distance is a compact layout assumption, not user-provided.
- A 20T/20T GT2 pair gives a 1:1 ratio. Change tooth counts before approval if a different ratio is required.
- A nominal 180 mm GT2 belt is derived for the initial layout. Final belt source, tension, and tooth count must be confirmed.
- The selected `belt_mid_plane_z` assumes the motor shaft length and pulley hub allow a 6 mm belt above a 6 mm plate. Confirm the exact motor shaft length and pulley hub dimensions before final CAD.
- A single 608 bearing is represented because the prompt requested a 608 bearing support. If the belt load or shaft overhang is significant, detail design should use paired bearings or an additional support, returning to layout review if the assembly graph changes.
- Bearing fit class, shaft retention, pulley set-screw flats, motor cable keep-out, and fastener stack lengths are not certified by the layout proxy.

## Proceed Gate

Layout verdict target: `ready_for_review`.

Review the rough layout for positioning, interfaces, and drivetrain structure. If the vertical shaft architecture, 70 mm center distance, 13.5 mm belt mid-plane, NEMA 17 mounting pattern, 608 bearing support location, GT2 pulley pair, and belt path are correct, say "proceed" and detail modeling can preserve these locked facts.

Allowed detail-stage changes after approval:

- Replace proxy bodies with sourced STEP/STP or detailed generated geometry.
- Add cosmetic fillets, chamfers, labels, and fastener head detail.
- Add motor wire keep-out and non-interfering cable routing.
- Add set-screw flats, retaining rings, and bearing retainers if they do not move locked axes or belt plane.
- Add motor slots for tension only if the approved nominal axis locations remain represented or the change returns to the proceed gate.

Changes requiring return to layout:

- Changing shaft orientation, center distance, belt plane height, pulley tooth count, drivetrain ratio, mounting face location, bearing support count, or assembly graph.
- Moving motor or output shaft axes.
- Replacing the single-bearing support with a different support topology.

## Downstream CAD Handoff

Target harness: build123d-compatible layout proxy adapter generated by Zen CAD runtime; downstream detail CAD can target build123d, CAD Skills/text-to-cad, CadQuery, FreeCAD, or another harness after proceed approval.

Instructions for downstream generation:

- Use low visual fidelity but high interface fidelity during layout.
- Preserve the locked layout facts exactly.
- Model base plate, motor envelope, two GT2 pulley pitch references, GT2 belt envelope, 608 bearing support, output shaft, and M3 fastener axes.
- Do not treat viewer screenshots as completion evidence; use source-level parameters, datums, labels, and measured axes/distances.
- Stop if source geometry or final part selection changes any approved locked layout fact.

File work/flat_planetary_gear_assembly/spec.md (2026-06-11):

# CAD Spec: Flat Planetary Gear Assembly

## Intent

Create a flat planetary gear assembly with separate sun, three planet, ring, carrier, and pin bodies. The current CAD artifact is a build123d STEP review model using module-locked involute gear geometry for the sun and planets, plus a negative involute cutter method for the internal ring gear. A premium-detail pass adds root fillets, raised hub bosses, ring lips, mount holes, carrier lightening holes, and filleted pin caps without changing locked mesh geometry. This is a stronger drivetrain-layout model than the earlier trapezoid proxy, but it is still not a load-rated or manufacturing-certified gearset.

## Coordinate System

- Units: millimeters.
- Root frame: `sun_axis`, origin at the sun gear axis.
- Base plane: XY gear plane.
- Up axis: +Z through all gear, carrier, and pin axes.
- Nominal pose: ring and sun are coaxial at world origin; planets and pins are arranged at 0, 120, and 240 degrees on a 42 mm radius circle.

## Parameter Contract

| Name | Value | Status | Source | Drives | Validation |
| --- | ---: | --- | --- | --- | --- |
| `planet_radius` | 42 mm | locked | user | planet and pin axis placement | `check_planet_radius` |
| `planet_count` | 3 | locked | user | repeated planet, pin, and carrier hole pattern | `check_separate_bodies`, `check_planet_radius` |
| `gear_module` | 2 mm | derived | `2 * planet_radius / (sun_teeth + planet_teeth)` | shared pitch system | `check_module_locked_ring_mesh` |
| `pressure_angle` | 14.5 deg | assumed | involute generator constraint for the 60T internal cutter | sun, planet, and ring cutter tooth profiles | `check_involute_teeth` |
| `sun_tooth_count` | 24 | assumed | layout assumption | sun involute tooth pattern | `check_involute_teeth` |
| `planet_tooth_count` | 18 | assumed | layout assumption | three planet involute tooth patterns | `check_involute_teeth` |
| `ring_tooth_count` | 60 | derived | `ring = sun + 2 * planet` | internal ring tooth spaces | `check_module_locked_ring_mesh` |
| `sun_pitch_radius` | 24 mm | derived | `module * sun_teeth / 2` | sun pitch reference | `check_planet_radius` |
| `planet_pitch_radius` | 18 mm | derived | `module * planet_teeth / 2` | planet pitch references | `check_planet_radius` |
| `ring_pitch_radius` | 60 mm | derived | `module * ring_teeth / 2` | internal ring pitch reference | `check_planet_radius` |
| `gear_thickness` | 6 mm | assumed | layout assumption | sun, planet, and ring body thickness | STEP bbox check |
| `sun_bore_diameter` | 8 mm | assumed | layout assumption | sun center bore | `check_ring_sun_coaxial` |
| `planet_pin_diameter` | 5 mm | assumed | layout assumption | planet bores, pin cylinders, carrier holes | `check_planet_radius` |
| `ring_outer_diameter` | 144 mm | assumed | layout envelope | ring body envelope | STEP bbox check |
| `ring_cutter_scale_xy` | 1.01 | derived | static backlash proxy | internal ring tooth-space clearance | `check_no_tooth_overlap` |
| `gear_root_fillet` | 0.1 mm | assumed | detail pass | sun, planet, and ring cutter tooth roots | `check_premium_detailing` |
| `sun_hub_boss_diameter` | 18 mm | assumed | detail pass | raised sun hub boss | `check_premium_detailing` |
| `planet_hub_boss_diameter` | 11.5 mm | assumed | detail pass | raised planet hub bosses | `check_premium_detailing` |
| `ring_mount_holes` | 6 holes on R68 mm | assumed | detail pass | ring mounting/detail holes | `check_premium_detailing` |
| `carrier_lightening_holes` | 6 holes on R30 mm | assumed | detail pass | carrier visual/weight relief | `check_premium_detailing` |

Derived pitch relationships:

- Sun/planet center distance: `24 + 18 = 42 mm`.
- Planet/ring center distance: `60 - 18 = 42 mm`.
- Ring tooth relation: `60 = 24 + 2 * 18`.
- Three-planet spacing condition: `(sun_teeth + ring_teeth) / 3 = 28`, an integer.

## Artifact Targets

- Maturity target: `detail_cad` review model from a layout-approved contract.
- CAD source intent: build123d with `bd_warehouse.gear.SpurGear`.
- Primary artifact: `layout_proxy_build123d.step`.
- Review artifacts: STEP generation inspection report, supplemental geometry report, viewer link, viewer snapshot PNG, layout snapshot PNG, proceed gate package.
- Source of truth: this Markdown spec and `package/cad_spec.json`; generated STEP and snapshots are derived evidence only.

## Parts And Roles

- `sun_gear`: 24T involute spur gear, centered at `sun_axis`.
- `planet_gear_1`, `planet_gear_2`, `planet_gear_3`: 18T involute planet gears centered on the locked 42 mm radius circle.
- `ring_gear`: fixed 60T internal ring gear made by subtracting a scaled 60T involute spur cutter from an annular blank; includes outer lips and six non-mesh mount holes.
- `carrier`: locator disk below the gear plane, with central bore, three pin holes, six lightening holes, and rounded outside edges.
- `pin_1`, `pin_2`, `pin_3`: separate locator pin cylinders coaxial with planet axes; each has a rounded stem and cap.

## Assembly Graph

- `sun_gear` and `ring_gear`: coaxial on the root +Z axis.
- `planet_gear_*` axes: parallel to +Z and positioned on the 42 mm radius circle.
- `pin_*` axes: coaxial with corresponding planet axes.
- `carrier`: centered on the root frame and patterned to the same three pin axes.

## Interface Primitives

- `sun_axis`: root +Z axis.
- `ring_axis`: coaxial +Z axis at origin.
- `planet_axis_1`: +Z axis at `(42, 0, 0)`.
- `planet_axis_2`: +Z axis at `(-21, 36.373, 0)`.
- `planet_axis_3`: +Z axis at `(-21, -36.373, 0)`.
- `carrier_pin_pattern`: three-hole pattern at radius 42 mm.
- `gear_pitch_references`: sun 24 mm, planet 18 mm, ring 60 mm pitch radii.
- `ring_internal_mesh`: 60T involute cutter scaled 1.01x in XY and subtracted from the ring blank; this creates static backlash in the review proxy.
- `premium_non_mesh_detail`: raised hub bosses, ring outer lips, mount holes, lightening holes, and pin caps stay outside the locked tooth contact envelopes.

## Motion And Drivetrain

The assembly represents a flat planetary stage layout. All rotating components use revolute +Z axes. Gear ratio references can be derived from sun 24T and ring 60T; with a fixed ring, the nominal carrier speed relation is `omega_carrier = omega_sun * sun / (sun + ring) = omega_sun * 24 / 84`. This review artifact does not certify torque, load, bearing strategy, lubrication, noise, or efficiency.

## Proxy Fidelity Policy

Preserve axes, pitch radii, center distance, separate body structure, carrier pin pattern, bores, and involute tooth-pattern presence. Ring backlash is represented by the scaled negative cutter. The premium-detail pass may add non-mesh shape detail, but must not alter gear centers, pitch radii, tooth counts, or Boolean no-overlap checks. Simplify material, tolerance stack, and detailed bearing/shaft interfaces.

## Locked Layout Facts

- `separate_bodies_locked`: sun, three planets, ring, carrier, and three pins remain separate logical CAD bodies.
- `planet_radius_locked`: planet and pin axes remain on a 42 mm radius circle.
- `gear_axes_parallel_locked`: all gear, carrier, and pin axes remain parallel to +Z.
- `involute_teeth_locked`: sun and planet gears use `bd_warehouse` involute SpurGear geometry; ring gear uses a matching negative involute cutter.
- `module_locked_ring_mesh_locked`: module 2 pitch system remains sun 24T, planet 18T, ring 60T with `Nr = Ns + 2Np`.
- `no_tooth_overlap_locked`: static Boolean common volume between all six meshing sun/planet and planet/ring pairs remains zero.
- `premium_detail_non_mesh_locked`: cosmetic/detail features remain outside the locked mesh envelopes.

## Inspection Plan

- Validate contract package schema.
- Generate and inspect layout proxy scene.
- Inspect build123d source carry-through.
- Generate STEP from build123d and re-import it for validity, bbox, volume, and feature-plan checks.
- Run supplemental build123d Boolean checks for all sun/planet and planet/ring mesh pairs.
- Inspect premium detailing carry-through: tooth root fillets, hub bosses, ring lips/mount holes, carrier lightening holes, pin caps, and unchanged bbox.
- Package viewer link and snapshot evidence.
- Package proceed gate with generated artifacts and inspection reports.

## Repair Loop

If a check fails, change the smallest responsible source, feature-plan parameter, datum, or artifact packaging step; regenerate affected outputs; rerun failed checks and dependent checks. If a repair requires changing the locked 42 mm planet radius, the 24/18/60 tooth-count relationship, separate-body structure, or +Z axes, return to the proceed gate instead of silently changing layout.

## Assumptions And Open Questions

- Pressure angle is 14.5 degrees because the current `bd_warehouse` involute generator rejects the 60T internal cutter configuration at 20 degrees under the chosen root/addendum settings.
- Ring tooth-space backlash is represented by scaling the negative ring cutter 1.01x in XY.
- The STEP is a static review model; it does not simulate rolling contact, load, dynamic backlash, or manufacturability.
- Some cylindrical edge rounds are torus-based build123d approximations rather than selector-derived topology fillets.
- Material, tolerances, carrier bearing strategy, ring mounting holes, and shaft interfaces are not yet locked.

## Proceed Gate

Review the STEP/viewer/snapshot for positioning, interfaces, drivetrain structure, and the new premium-detail treatment. If the separate bodies, +Z axes, 42 mm planet circle, 24/18/60 tooth-count relationship, internal ring mesh, premium non-mesh details, and zero-overlap Boolean report are acceptable, say `proceed` before production-oriented refinement.

## Downstream CAD Handoff

Target harness: build123d. Preserve all locked layout facts and stop if detail modeling would move planet axes off the 42 mm radius circle, change the module/tooth-count relationship, merge bodies, remove internal ring mesh evidence, or change the root frame.

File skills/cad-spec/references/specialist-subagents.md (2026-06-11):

# Specialist Subagents

Read this when the user asks to continue from spec into CAD work, or when the assembly is complex enough that layout, parameters, interfaces, motion, generation, inspection, and review should be separated.

## Delegation Rule

Spawn subagents only when the harness supports them and the subtask is bounded. The lead agent keeps ownership of the CAD spec, locked facts, and final user-facing answer.

For generated CAD or repair tasks, the lead must create a Subagent Dispatch Plan before editing geometry. If subagents are available, spawn the planned roles. If they are not available, state `Subagent status: unavailable; using sequential fallback roles` and run the same roles sequentially in this order: layout, interface, parameter, motion, CAD generation, visual review, engineering review, CAD review, then repair.

Good subagent tasks:

- independent enough to run without blocking the lead;
- small enough to return a concrete artifact or review note;
- tied to named spec sections and locked facts;
- tied to expected parameters, artifacts, or checks;
- limited to one specialty.

Poor subagent tasks:

- "make the whole CAD";
- open-ended catalog crawling;
- vague quality review without locked facts;
- any task that can silently change approved layout facts.

## Recommended Roles

### Layout Specialist

Ask for:

- root component and root frame;
- part-local frames;
- assembly graph;
- contact and connection relationships;
- locked layout facts;
- proceed-gate review notes.

### Interface Specialist

Ask for:

- interface signatures for common component families;
- mounting faces, bolt patterns, bores, shafts, rails, belts, envelopes;
- assumptions labeled `trusted_for_layout`, `must_confirm_before_detail`, or `must_confirm_before_final`;
- facts that should not block layout proxy generation.

### Parameter Specialist

Ask for:

- named dimensions and motion controls;
- units, default values, allowed ranges, and locked/assumed/derived status;
- which part, feature, datum, joint, or clearance each parameter drives;
- validation targets for critical parameters;
- derived relationships that should replace visual tuning.

### Motion Specialist

Ask for:

- joint types and axes;
- travel limits;
- gear, belt, screw, linkage, or coupler relationships;
- keep-outs and collision-sensitive envelopes;
- drivetrain facts that must be locked before detail modeling.

### CAD Generator

Ask for:

- low-detail layout proxy first;
- simple solids where surface fidelity is not important;
- explicit preservation of locked layout facts;
- source path, primary artifact path, assumptions, and checks run;
- stop if a locked fact must change.

### Inspection Specialist

Ask for:

- source-level parameter and label checks;
- generated artifact facts, bounding boxes, planes, and axes;
- targeted measurements, frame checks, mate checks, or diffs where supported;
- snapshot or viewer review when available;
- failed/skipped checks with reasons and smallest repair step.

### Visual Reviewer

Ask for:

- multi-view snapshot review using isometric, orthographic, close-up, xray, section, or isolated views when available;
- floating body, unintended interference, clearance, fastening, mesh/alignment, and implausible load-path findings;
- issue ids, suspected part ids, view/artifact references, and visual evidence;
- a measurable check that should be added or rerun for each visual concern.

### Engineering Reviewer

Ask for:

- fastener engagement, boss depth, shaft/bore fit, bearing coaxiality, pulley/gear pitch plane, gear center distance, belt centerline, wall thickness, support, and assembly access concerns;
- engineering-rule checks that can be evaluated from source parameters, STEP facts, or targeted measurements;
- repair candidates that change the smallest source-level parameter, datum, placement, feature, or mate;
- stop conditions when a repair would change locked layout facts.

### CAD Reviewer

Ask for:

- comparison against the parameter contract and inspection plan;
- comparison against locked layout facts;
- interface and motion relationship checks;
- drift from the proceed gate;
- allowed versus disallowed simplifications;
- concise blockers and smallest correction steps.

## Lead Reconciliation

After subagents return:

1. Merge only facts that are supported by the spec or clearly marked assumptions.
2. Resolve conflicts in frames, axes, dimensions, or clearances before handoff.
3. Merge the parameter contract, artifact targets, inspection plan, and repair rules.
4. Update locked layout facts explicitly.
5. Keep rejected or uncertain facts in open questions.
6. Do not proceed to detail CAD until positioning, interface, and inspection blockers are resolved.

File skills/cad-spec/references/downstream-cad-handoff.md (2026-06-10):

# Downstream CAD Handoff

Read this when handing a CAD-native spec to the active CAD harness, `$cad`, text-to-cad, build123d, CadQuery, FreeCAD, or another generator.

## Handoff Rule

The handoff should tell the generator what to build and what not to optimize yet.

For layout:

```text
Generate a low-detail layout proxy from this spec. Preserve all locked interface facts, coordinate frames, axes, center distances, pitch references, clearances, and motion relationships. Simplify surface detail aggressively. Return artifacts suitable for proceed review.
Use named parameters for critical dimensions and return checks that prove the locked facts survived generation.
```

For detail after explicit proceed approval:

```text
Upgrade visual and manufacturing-relevant detail while preserving the approved locked layout facts. If any locked fact must change, stop and return to layout review.
```

## Handoff Fields

Include:

- target harness or tool if known;
- target output type: layout proxy, detail model, final package;
- source/spec path or pasted spec;
- desired CAD source format;
- primary output artifact;
- secondary outputs only when requested or supported;
- parameter contract;
- native feature plan when build123d should generate holes, bores, patterns, chamfers, fillets, or simplified gears;
- validation/review expectations;
- repair loop expectations;
- locked facts;
- proxy simplifications allowed;
- unresolved assumptions.

## Codex Handoff

Codex can edit files and run local tools. Ask it to:

- create or update explicit CAD source;
- keep the spec and generated source separate;
- preserve named parameters and derived relationships;
- run available deterministic checks;
- return artifact paths, checks run, skipped checks, repair attempts, and limitations;
- avoid final claims unless the required final checks are explicitly requested and completed.

## text-to-cad / `$cad` Handoff

When `$cad` from `earthtojake/text-to-cad` is available, hand it the spec and ask for:

- STEP-first output;
- build123d/Python source when generating new geometry;
- named parameters, datums, labels, or source-level joints where useful;
- `scripts/inspect refs --facts --planes --positioning` or equivalent inspection;
- targeted measurements, frames, mating deltas, diffs, or snapshot review when relevant and supported;
- CAD Viewer handoff when available.

Do not require `$cad` to perform sourcing, BOM, final engineering reports, or procurement evidence for layout work.

## Zen CAD build123d Generation

When build123d is the active target, use the repo runner instead of writing a one-off generator command:

```bash
python3 tools/run_contract_pipeline.py --package <contract-package> --out <run-dir> --target-harness build123d
```

This produces generated source, a primary STEP artifact, source inspection, CAD generation inspection, viewer link artifact, proceed gate, and review bundle. Treat the STEP as a layout/detail candidate that still needs any skipped topology, source-lock alignment, or manufacturing checks before final claims.

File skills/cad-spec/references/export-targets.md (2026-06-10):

# Export Targets

Read this when a CAD spec will be handed to a generator, reviewer, viewer, or downstream packaging step.

## Principle

A CAD spec should state artifact intent before generation starts. The downstream agent should know what source to create, which CAD artifact is primary, which outputs are secondary, and what review evidence is expected.

Zen CAD does not require every environment to use a specific CAD kernel. When build123d is available, Zen CAD can execute generated source into a first-pass STEP artifact itself. When another active tool supports STEP, treat STEP/STP as the primary exchange artifact unless the user asks for a different target.

## Target Maturity

State one maturity target:

- `layout_proxy`: low surface detail, high interface and positioning fidelity;
- `detail_cad`: approved layout with improved surface, feature, and packaging quality;
- `final_package`: requested exports plus completed checks available in the active toolchain.

Do not request final-package polish before the layout proxy has passed the proceed gate.

## Artifact Contract

Include:

- CAD source intent: build123d, CadQuery, FreeCAD, native tool file, or unknown;
- primary artifact: usually STEP/STP when supported;
- secondary artifacts: STL, DXF, 3MF, native GLB, screenshots, or viewer links only when requested or supported;
- review artifacts: deterministic inspection summary, snapshot packet, viewer handoff, or equivalent;
- source-of-truth rule: source and spec remain authoritative; generated files are derived.

## Explicit Targets

Ask downstream generators for explicit file paths when they create files. Avoid vague instructions such as "generate everything in the folder." Do not request directory-wide generation unless the user explicitly asks for batch conversion.

For a new model, the handoff should name:

- source path or source naming intent;
- primary CAD artifact path or naming intent;
- whether Zen CAD should run the build123d generation phase locally;
- whether the spec should carry a native `cad_feature_plan` for holes, bores, patterns, chamfers, fillets, or simplified gears;
- whether a local viewer link should be packaged after STEP generation;
- expected top-level labels or assembly children;
- expected bounding box or critical measurements;
- inspection and snapshot requirements supported by the tool.

## Secondary Outputs

Secondary exports should branch from accepted geometry. Do not let an STL, visual render, or mesh-only output become the source of truth for a mechanical assembly unless the user explicitly chooses that workflow.

If the active tool cannot create a requested secondary export, report the missing capability and keep the primary CAD artifact reviewable. Local viewer links should point at generated CAD artifacts when possible, but they remain review evidence only.

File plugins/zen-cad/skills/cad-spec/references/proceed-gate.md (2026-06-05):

# Proceed Gate

Read this when the spec will be used to generate a layout proxy before detail modeling.

## Purpose

The proceed gate is the UX checkpoint between low-detail layout and high-detail CAD. It tells the user exactly what to inspect before approving detail work.

## Gate Content

Write a proceed gate with:

- layout verdict target: `ready_for_review`, `needs_clarification`, or `blocked`;
- inspection checklist;
- locked facts that will be preserved after approval;
- allowed detail-stage changes;
- changes that require returning to layout;
- known assumptions and unresolved risks.

## User-Facing Prompt

Use direct language:

```text
Review the rough layout for positioning, interfaces, and drivetrain structure.
If the axes, center distances, belt/gear/rail relationships, clearances, and mounting faces are correct, say "proceed" and detail modeling can preserve these locked facts.
```

Do not ask the user to approve surface quality during layout unless surface quality controls an interface.

## Approval Record

If the harness has a project file, write the approved locked facts there. If no project file exists, include them in the conversation handoff. When using the repo runtime, record the decision as a `proceed_approval` artifact before generating a detail handoff. The important part is that detail generation receives the locked facts explicitly and can prove they match the reviewed proceed package.

## Return To Layout

Return to layout review when detail modeling would change:

- root frame;
- part transforms;
- joint axes;
- center distances;
- pitch references;
- belt plane;
- mounting face positions;
- bolt pattern positions;
- clearance envelopes;
- travel range;
- part count or assembly graph.

Detail modeling may change visual fidelity, supplier body contours, fillets, chamfers, threads, labels, and secondary exports if locked facts remain unchanged.

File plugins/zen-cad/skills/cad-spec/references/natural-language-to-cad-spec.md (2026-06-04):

# Natural Language To CAD Spec

Read this when converting a user's prose into a CAD-native spec. Do not require the user to provide JSON, YAML, or a formal requirements document.

## Goal

Extract the mechanical facts that control CAD generation:

- object or assembly being modeled;
- intended first-pass maturity: layout proxy, detail, or final handoff;
- units and coordinate assumptions;
- functional parts and repeated families;
- fixed and moving relationships;
- critical dimensions, missing dimensions, and safe assumptions;
- named parameters, derived relationships, and validation targets;
- intended CAD source and primary artifact targets;
- interfaces that locate parts;
- motion or drivetrain behavior;
- validation or user-review targets.

## Spec Style

Write Markdown with clear section headings. Use tables when many parts or interfaces must be compared. Use compact structured bullets for geometry facts.

Good:

```text
- Motor shaft axis: +X, origin at motor face center.
- Pulley pitch plane: XZ plane at Y = 0, centered on shaft axis.
- Belt span: upper/lower straight spans parallel to X.
```

Weak:

```text
- Put the pulley on the motor and route the belt around it.
```

## Clarification Policy

Ask one focused question only when:

- no physical scale is provided;
- a mating interface is named but its geometry is unknown;
- a motion range, travel, ratio, or axis is impossible to infer;
- the design is safety-critical, load-bearing, pressure-bearing, medical, or compliance-bound;
- a downstream output depends on an absent source file.

Otherwise proceed with explicit assumptions. Mark each assumption as one of:

- `layout_assumption`: acceptable for first-pass layout;
- `must_confirm_before_detail`: can affect detail CAD;
- `must_confirm_before_final`: affects sourcing, rating, manufacturing, or final claims.

## Internal Readiness Check

Before handing off to CAD generation, confirm the spec names:

- root frame;
- units;
- parameter contract;
- artifact maturity and primary output intent;
- fixed component;
- part list;
- interface primitives for all positioning-sensitive relationships;
- inspection plan;
- repair loop;
- proxy fidelity policy;
- locked layout facts;
- proceed gate.

If any of these are missing, the spec is not ready for layout CAD.

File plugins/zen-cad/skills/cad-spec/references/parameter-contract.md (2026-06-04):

# Parameter Contract

Read this when a CAD spec has dimensions, repeated features, motion controls, configurable variants, or downstream CAD generation.

## Principle

Parameters are part of the model contract. They should make design intent traceable from the user's prose to generated geometry, inspection targets, and later detail upgrades.

A good parameter says what it controls, which facts it must preserve, and how the generated CAD can prove it behaved correctly.

## Required Parameter Fields

Use a compact Markdown table or bullet list with these fields:

- name;
- units or dimensionless status;
- default or selected value;
- allowed range when meaningful;
- locked status: locked, assumed, or derived;
- source: user, standard default, derived constraint, or temporary layout assumption;
- drives: named part, feature, datum, interface, joint, clearance, or motion;
- validation: expected bounding box, distance, mate, frame, angle, count, or visual review.

## Naming

Use semantic names:

- `wall_thickness`, `bearing_clearance`, `hinge_angle_deg`, `gear_ratio`, `bolt_circle_diameter`;
- `rail_spacing`, `shaft_center_distance`, `lid_gap`, `travel_limit`, `tooth_count`.

Avoid untraceable names such as `offset2`, `magic_scale`, `fix_angle`, or `temp_shift` unless the user's source already uses that term.

Encode units in the name only when ambiguity is likely, especially angle, time, clearance, and normalized travel.

## Independent And Derived Values

Separate user-controlled inputs from derived constraints.

For assemblies and mechanisms, derive placement from:

- pivots, axes, centers, and part-local frames;
- link lengths, pitch circles, belt pitch lines, screw pitch, rail spacing, and mounting faces;
- clearances, gasket gaps, bearing seats, shaft bores, and fastener patterns.

Do not tune transforms by sight. If a parameter changes an assembly position, the spec must state the datum or constraint that recomputes the position.

## Layout Versus Detail

Layout parameters may control simplified boxes, cylinders, envelopes, and proxy teeth. Detail parameters may later refine fillets, wall transitions, tooth profiles, chamfers, rib shapes, or cosmetic surfaces.

Do not let detail parameters change locked layout facts. If a detail change needs a new center distance, bore axis, pitch reference, mounting face, or motion limit, return to the proceed gate.

## Parameter Review

Before CAD generation, check:

- every locked fact is represented by a parameter, datum, or explicit relationship;
- every repeated feature is derived from count, pitch, radius, offset, or pattern axis;
- every moving relationship has a pose or travel parameter;
- assumptions are marked as not locked;
- validation targets cover default values and important boundary poses.

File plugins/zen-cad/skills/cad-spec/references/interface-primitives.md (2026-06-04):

# Interface Primitives

Read this when a spec needs mating surfaces, shafts, bores, bolt patterns, belt/gear references, rails, slots, or fastening features.

## Principle

Assemblies are mostly governed by simple interface primitives. Name those primitives explicitly so low-detail CAD can still be mechanically meaningful.

## Common Primitives

Use these names where applicable:

- `datum_plane`: mounting face, seating face, lid underside, bracket face.
- `axis`: shaft centerline, hinge axis, pulley axis, bearing axis, screw axis.
- `cylinder`: bore, shaft, boss, bearing seat, spacer, wheel, roller.
- `bolt_pattern`: count, diameter, circle/rectangle pattern, hole size, orientation.
- `slot`: width, length, end radii, travel axis, centerline.
- `rail`: guide axis, carriage envelope, datum face, travel range.
- `pitch_circle`: gear, pulley, sprocket, or timing pulley reference.
- `belt_plane`: belt mid-plane, width envelope, span direction, pulley alignment.
- `keep_out`: volume or envelope that detail geometry must not invade.
- `clearance`: minimum gap, nominal gap, or intentional interference.

## Interface Signature Shape

When a standard interface is known, write a compact signature instead of a full catalog part:

```text
Interface signature: NEMA17 face
- frame size: 42.3 mm nominal
- pilot diameter: 22 mm
- shaft diameter: 5 mm
- mount pattern: 4 holes on 31 mm square
- shaft axis: normal to motor face
```

Signatures are layout facts, not procurement proof. They can drive layout proxies before supplier STEP files exist.

## Quality Rules

- A proxy may simplify visual geometry but must preserve interface primitive dimensions.
- A standard part may be represented by an envelope in layout when the interface signature is sufficient.
- A downstream CAD generator must not infer a mating axis from appearance when the spec can name it.
- If an interface controls motion or fit, give it an id so validation and proceed review can reference it.

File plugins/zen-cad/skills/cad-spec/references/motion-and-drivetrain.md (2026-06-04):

# Motion And Drivetrain

Read this when the design moves or transmits force through belts, pulleys, gears, screws, sliders, rails, shafts, bearings, or linkages.

## Required Motion Facts

For every moving relationship, state:

- joint type: fixed, revolute, prismatic, cylindrical, hinge, slider, belt, gear mesh, screw, linkage;
- moving frame and fixed frame;
- axis direction in the root frame;
- nominal pose for the first CAD artifact;
- travel or rotation limits;
- center distance or offset;
- clearance envelope;
- driven and passive components;
- ratio, pitch, lead, or tooth count when known;
- assumptions that must be confirmed before detail or final.

## Belt And Pulley Specs

For belt-driven layouts, define:

- belt pitch;
- belt width;
- belt mid-plane;
- pulley axes;
- pulley pitch diameter or tooth count if known;
- center distance;
- straight-span direction;
- tensioning/idler strategy;
- clearance around moving belt spans.

The layout proxy may use smooth cylinders or coarse teeth, but pitch plane, axes, center distance, and belt span envelopes must be correct.

## Gear Specs

For gear layouts, define:

- gear type;
- module or pitch;
- tooth count;
- pitch diameter;
- shaft axes;
- center distance;
- mesh plane;
- intended ratio;
- backlash or clearance assumption.

The layout proxy may use simplified teeth, but pitch circles and shaft axes must be correct.

## Rail, Screw, And Slider Specs

For linear motion, define:

- travel axis;
- carriage frame;
- rail/guide datum faces;
- screw or belt drive axis;
- end stops or travel limits;
- moving envelope and keep-outs;
- coupling to motor or driven element.

## Reporting

Separate motion facts from engineering claims. A CAD spec can define geometry and kinematics; it does not prove torque, speed, life, stiffness, backlash, thermal behavior, or safety without downstream analysis.

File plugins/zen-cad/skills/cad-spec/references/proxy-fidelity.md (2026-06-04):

# Proxy Fidelity

Read this when the first CAD artifact should be a low-detail layout model.

## Principle

A layout proxy is allowed to look rough. It is not allowed to be vague about interfaces.

## May Simplify

Layout proxies may simplify:

- cosmetic fillets and chamfers;
- smooth curvature;
- fine tooth profiles;
- thread geometry;
- cable sweeps;
- surface texture;
- manufacturing reliefs;
- exact supplier body contours;
- high segment counts;
- non-interface labels or decorative detail.

## Must Preserve

Layout proxies must preserve:

- coordinate frames;
- mating planes;
- shaft and bore axes;
- mounting hole patterns;
- center distances;
- pitch circles and pitch planes;
- belt/gear/chain span envelopes;
- rail or slot travel axes;
- clearances and keep-outs;
- joint degrees of freedom;
- part transforms;
- dimensions that affect proceed review.

## Proxy Labels

Every unresolved proxy should state:

- what real item or final geometry it stands in for;
- which interfaces are trustworthy;
- which dimensions are approximate;
- what must be replaced or refined after proceed;
- whether detail modeling may change it without returning to layout review.

## Downstream Instruction

Tell CAD generators explicitly:

```text
Use low visual fidelity but high interface fidelity. Do not spend time on final fillets, accurate tooth profiles, cosmetic curves, or supplier body contours during layout. Preserve the listed locked facts exactly.
```

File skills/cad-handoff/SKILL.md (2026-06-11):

---
name: cad-handoff
description: Convert a CAD-native spec into a concise downstream brief for a CAD-generation harness. Use for Codex, text-to-cad/$cad, build123d, CadQuery, FreeCAD, or other generators, especially when preserving layout locked facts, interface frames, replacement plans, detail shape plans, parameter contracts, feature plans, inspection plans, and repair loops through CAD generation and detail modeling.
version: 1.1.0
---

# CAD Handoff

## Purpose

Use this skill after `cad-spec` has produced a CAD-native spec and the next step is to create, inspect, repair, or update geometry. For `build123d` targets, Zen CAD can execute generated source into a first-pass STEP artifact. For approved detail handoffs targeted at CAD Skills/text-to-cad, this skill can also package a downstream prompt bundle.

This skill is adapter-specific. Keep harness names, `$cad`, file paths, tool launchers, and environment details here instead of in the core `cad-spec` skill.

## Use This Skill When

Use it when:

- the user wants to proceed from spec to CAD;
- a layout proxy should be generated from locked facts;
- a generated build123d source file should be executed into a primary STEP artifact;
- a detail model should preserve an approved layout;
- source-locked STEP/STP or detail CAD should replace proxy geometry through interface-frame mapping;
- custom detail CAD should be generated from locked facts and user shape intent;
- downstream generation needs explicit source, STEP/STP, snapshot, viewer, or secondary export targets;
- inspection or repair expectations must be carried into the generator prompt;
- visual inspection and engineering-rule repair expectations must be preserved through generation;
- the target harness is Codex, text-to-cad, build123d, CadQuery, FreeCAD, or unknown;
- generated STEP artifacts should be paired with local viewer links for proceed review.

## Workflow

1. Read the CAD spec and identify target maturity: layout, detail, or final.
2. Identify the downstream harness/toolchain.
3. State the Subagent Dispatch Plan for generation/review/repair, including explicit sequential fallback if subagents are unavailable.
4. Preserve locked facts verbatim in the handoff.
5. Preserve the parameter contract and mark locked, assumed, and derived values.
6. State source intent, primary artifact, secondary outputs, and review artifacts.
7. State proxy simplifications allowed for layout.
8. State deterministic checks, snapshot/viewer expectations, and skipped-check reporting.
9. State visual inspection requirements for fastening, clearance, floating body, interference, mesh/alignment, and engineering plausibility issues.
10. State source-of-truth, generated files, repair attempts, and claims that must not be made.
11. State the repair loop and when the generator must stop and return to layout review.
12. For replacement work, include interface frames, source frames, frame mapping, transform plan, and post-replacement locked-fact checks.
13. For constrained custom detail work, include protected zones, shape intent, manufacturing assumptions, and detail-shape inspection checks.
14. For `build123d` targets, run `tools/generate_cad_artifact.py` or the runner's build123d generation step before proceed review.
15. For generated STEP artifacts, include `tools/package_viewer_link.py` output or the runner's `viewer_link.html` in proceed review when a local viewer is available.
16. For an approved `text-to-cad` handoff packet, package the prompt bundle with `tools/package_text_to_cad_bundle.py`.

## Handoff Skeleton

```text
Task: Generate <layout proxy | detail CAD> from the attached CAD spec.
Primary goal:
Source-of-truth:
Generated files:
Locked facts:
Subagent dispatch plan:
Parameter contract:
Artifact targets:
Feature plan:
Interface frames:
Replacement plan:
Detail shape plan:
Allowed simplifications:
Required outputs:
Required checks:
Visual/engineering review:
Validation actually run:
Skipped checks and reasons:
Snapshot/viewer evidence:
Repair loop:
Repair attempts:
Stop conditions:
Known assumptions:
Claims not made:
```

## Non-Negotiables

- Do not hide locked facts in a summary; include them explicitly.
- Do not drop the parameter contract when moving from spec to generator prompt.
- Do not drop the Subagent Dispatch Plan when moving from spec to generator prompt; if subagents are unavailable, state the sequential fallback explicitly.
- Do not ask for high-fidelity geometry during layout unless the user requested it.
- Do not treat a screenshot or viewer link as a substitute for geometry checks.
- Do not close a generated assembly review while visible fastening, clearance, floating body, interference, or mesh/alignment concerns remain unclassified.
- Do not validate generated CAD by git diff, file size, or generated-file churn.
- Do not let the downstream generator change approved layout facts during detail.
- Do not let replacement geometry move locked interface frames; move the source/detail geometry into the approved layout instead.
- Do not let shape intent override protected zones or clearance envelopes.
- Do not claim final readiness unless the downstream tool actually produced the required outputs.
- Do not treat Zen CAD's first-pass STEP export as supplier-verified or manufacturing-ready geometry.
- Do not generate CAD, STEP/STP, snapshots, or viewer links while packaging a text-to-cad prompt bundle.

## References

- `references/harness-briefs.md` — Codex, `$cad`, and generic handoff templates.
- `references/runtime-contract.md` — keeping core specs kernel-neutral while adapter prompts map to active runtime tools.
- `references/text-to-cad-adapter-contract.md` — approved handoff to CAD Skills/text-to-cad prompt bundle contract.

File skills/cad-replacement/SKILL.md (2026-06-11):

---
name: cad-replacement
description: Replace layout proxy parts with source-locked STEP/STP, user-provided detail CAD, or generated detail candidates while preserving locked facts. Use for step.parts replacement, source-lock alignment, proxy-to-source interface frame mapping, replacement_plan artifacts, datum/mate transform solving, and post-replacement inspection before proceed or final claims.
---

# CAD Replacement

Use this skill after `cad-spec` has produced a layout proxy scene and a part should be replaced by sourced or detailed CAD. The goal is not visual substitution. The goal is to keep the proxy's locked interface facts fixed while replacing its rough geometry.

## Required Workflow

1. Read the CAD spec, layout proxy scene, source-lock evidence, and any detail candidate handoff.
2. Load `references/interface-frame-contract.md` and `references/replacement-plan.md`.
3. Identify the proxy interface frames that drive replacement: mounting planes, bore/shaft axes, bolt patterns, pitch references, clearance envelopes, and motion axes.
4. If required proxy frames are missing or only described in prose, stop and write the missing frame contract before replacing geometry.
5. Resolve the source geometry. Prefer checksum-recorded local STEP/STP from `source_lock_evidence`; use remote locators only as review references unless the task explicitly allows download.
6. Define source interface frames for the sourced/detail geometry. Use family templates only when the template actually covers the source part.
7. Compute replacement placement from frame mapping: `world_source = world_proxy_frame * inverse(source_frame)`.
8. Write or update a `replacement_plan` artifact that names every transform, locked fact, required check, and blocked item.
9. Generate or update CAD source only after the replacement plan is complete.
10. Inspect the transformed geometry against locked facts. Do not proceed on screenshots, file size, bbox-only checks, or apparent visual alignment.

## Hard Rules

- Do not move a locked proxy frame to fit a source STEP.
- Do not silently accept source geometry whose interface frames disagree with the approved layout.
- Do not claim final readiness while replacement alignment, mate, clearance, or source-lock checks are skipped.
- If a source part cannot be aligned without changing a locked fact, return to the proceed gate.

## Outputs

- `interface_frame` artifacts for proxy frames and source/detail frames when they are not already present.
- `replacement_plan` with one replacement entry per part.
- Inspection report that measures post-replacement axes, planes, bolt patterns, clearances, and failed/skipped checks.

## References

- `references/interface-frame-contract.md` — frame fields, tolerances, and source/proxy frame rules.
- `references/replacement-plan.md` — replacement plan status, transform contract, and pass/fail criteria.

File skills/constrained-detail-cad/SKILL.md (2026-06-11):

---
name: constrained-detail-cad
description: Generate custom/detail CAD from locked layout facts and user shape intent while preserving protected interface frames, clearances, mounting datums, bores, shafts, bolt patterns, pitch references, and motion envelopes. Use for custom brackets, plates, covers, housings, adapters, and generated detail_shape_plan artifacts.
---

# Constrained Detail CAD

Use this skill when a custom part needs a user-desired shape, but the layout proxy has already established facts that cannot move. Standard/catalog parts should usually use `cad-replacement`; custom parts should use this constrained generation workflow. In this workflow, locked facts are hard constraints and style is negotiable.

## Required Workflow

1. Read the CAD spec, layout proxy scene, locked facts, interface frames, and user shape request.
2. Load `references/detail-shape-plan.md`.
3. Separate the part into protected interface zones, functional structure zones, and freeform/style zones.
4. Convert the user's desired appearance into `shape_intent`: style, manufacturing method, minimum wall, preferred fillets/chamfers, and avoid list.
5. Write or update a `detail_shape_plan` artifact before generating CAD.
6. Generate geometry by placing protected interface features first, then structural features, then style/freeform features.
7. Export a detail candidate and inspect it against locked facts. The user's requested shape is allowed only inside the feasible space left by protected zones and clearance rules.
8. Repair source-level causes when checks fail. Do not tune visually or move locked interfaces to make the shape look better.

## Hard Rules

- Locked facts are hard constraints; shape intent is a soft constraint.
- Protected zones cannot be cut, moved, resized, or obscured by style features.
- A generated detail part cannot proceed until bores, shafts, bolt patterns, mounting planes, clearances, and relevant motion envelopes are measured after export.
- If the requested shape conflicts with a locked fact, report the conflict and propose a shape adjustment instead of changing the locked fact.

## Outputs

- `detail_shape_plan` for every generated custom part.
- Generated CAD source and STEP/STP detail candidate when the active CAD harness supports generation.
- Inspection report with locked fact measurements and skipped checks.

## References

- `references/detail-shape-plan.md` — detail shape plan structure, zone model, feature ordering, and inspection gates.

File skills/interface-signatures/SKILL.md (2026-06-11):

---
name: interface-signatures
description: Define standard mechanical interface signatures for layout CAD without requiring full supplier geometry. Use for motors, belts, pulleys, bearings, rails, screws, shafts, bolt patterns, envelopes, and reusable mating facts that drive low-detail assembly proxies.
version: 1.0.2
---

# Interface Signatures

## Purpose

Use this skill to represent the interface facts of common components before full supplier geometry exists. It supports layout-first CAD by giving the generator trustworthy mating dimensions, axes, envelopes, and clearance assumptions.

This skill does not prove ratings, procurement identity, material, certification, or supplier geometry. When a standard/catalog part needs final-stage source evidence, create a separate `source_lock_evidence` artifact instead of upgrading the layout signature.

## Use This Skill When

Use it when a layout spec mentions:

- motors, servos, gearmotors, encoders, sensors, or connectors;
- belts, pulleys, gears, sprockets, chains, shafts, bearings, bushings, rails, or screws;
- fasteners, inserts, bolt patterns, clearance holes, counterbores, or standoffs;
- a known family such as NEMA motors, GT2 belts, M-series screws, 608 bearings, or linear rail carriages.

## Workflow

1. Identify the component family.
2. Check `registry/interfaces/index.json` for a known layout-ready signature.
3. If no exact registry or project model is available, record the miss and proceed with a documented envelope when layout is not fit-critical.
4. Extract only interface facts needed for layout.
5. Mark each fact as standard, assumed, user-provided, or must-confirm.
6. Define envelope geometry when useful.
7. Name checks that can validate the interface in generated CAD.
8. State what a proxy may simplify.
9. State what needs datasheet or supplier evidence before final claims.
10. For final-stage sourcing, record explicit source-lock evidence separately; keep interface signatures marked as layout-only references.

## Signature Shape

Use compact Markdown:

```text
Interface signature: <family/name>
- trusted_for_layout: yes
- source: common standard | user-provided | assumed | project registry
- primary axes:
- mounting datums:
- critical dimensions:
- validation targets:
- envelope:
- proxy may simplify:
- must confirm before final:
```

## Non-Negotiables

- Do not invent ratings.
- Do not call a signature supplier-verified.
- Do not let a missing STEP file block layout when the interface signature is enough.
- Do not start broad catalog crawling before trying the built-in registry and documented envelope path.
- Do not use an interface signature for final procurement identity.
- Do not treat `interface_signature_refs` inside source-lock evidence as proof; they are only layout references.

## References

- `references/common-families.md` — common component families and the facts usually needed for layout.
- `references/signature-quality.md` — quality labels and finalization boundaries.
- `references/source-lock-evidence.md` — final-stage source evidence boundary for step.parts, manufacturer URLs, datasheets, and user-provided files.

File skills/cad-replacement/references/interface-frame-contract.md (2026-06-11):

# Interface Frame Contract

An interface frame is the machine-readable anchor that makes proxy replacement possible. It is stronger than a prose datum statement and weaker than final engineering certification.

## Required Frame Fields

Every replacement-critical frame should name:

- `id`: stable frame id such as `bearing_proxy.bore_frame`;
- `part_id`: the proxy/source/detail part it belongs to;
- `role`: mounting plane, bore axis, shaft axis, bolt pattern, pitch reference, clearance envelope, motion axis, or custom;
- `frame.origin`: XYZ origin in millimeters;
- `frame.x_axis`, `frame.y_axis`, `frame.z_axis`: unit basis vectors;
- `locked_fact_refs`: the locked facts this frame preserves;
- `tolerance`: position, angle, and optional diameter/clearance tolerances.

Use `schemas/interface_frame.schema.json` for standalone frame artifacts.

## Proxy Frames

Proxy frames come from the approved layout contract and are hard constraints after proceed approval. They should be generated from interface signatures, layout parameters, and locked facts, not from visual guessing.

If a proxy frame is missing for a replacement-critical fact, block replacement and repair the contract first.

## Source Frames

Source frames describe the matching interface on a sourced STEP/STP or detail CAD candidate. They can come from:

- explicit user-provided frame metadata;
- source-lock evidence extensions;
- family templates for known parts such as bearings, NEMA motors, rails, pulleys, gears, and fasteners;
- measured geometry from an imported STEP when the active CAD harness can inspect faces, cylinders, and patterns.

Do not assume a source STEP origin is the desired assembly placement.

## Alignment Rule

For each replacement, compute:

```text
world_source = world_proxy_frame * inverse(source_frame)
```

When multiple frames constrain the same replacement, solve the best transform and report residuals. A residual over tolerance blocks proceed.

## Required Checks

Minimum checks after transformation:

- frame origin delta within `position_mm`;
- axis angle delta within `angle_deg`;
- bore/shaft/pitch/bolt dimensions within declared tolerance;
- clearance envelopes still satisfied;
- relationships depending on the part still reference the same locked facts.

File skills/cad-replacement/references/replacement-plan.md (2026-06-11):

# Replacement Plan

A replacement plan is the contract between the approved layout proxy and the sourced/detail geometry that replaces it.

Use `schemas/replacement_plan.schema.json`.

## Status

- `blocked_missing_proxy_frame`: the layout proxy lacks required machine-readable frames.
- `blocked_missing_source_frame`: sourced/detail CAD lacks matching interface frames.
- `alignment_ready`: transforms are computable, but geometry has not been inspected after placement.
- `inspection_required`: CAD source has been prepared and post-replacement checks must run.
- `failed`: inspection found locked fact drift, clearance loss, or unresolved source mismatch.
- `passed`: all required post-replacement checks passed.

## Replacement Entry

Each entry should include:

- `part_id`;
- `mode`: `source_step`, `generated_detail`, or `manual_detail`;
- `source_lock_id` or `detail_shape_plan_id` when applicable;
- `proxy_frame_id`;
- `source_frame_id`;
- `transform`;
- `locked_fact_refs`;
- `required_checks`;
- `status`.

## Pass Criteria

The replacement may enter proceed review only when:

- all required proxy and source frames exist;
- every transform is explicit;
- source geometry has been imported or generated;
- post-transform inspection measured the locked facts;
- skipped checks have explicit reasons and do not affect proceed-critical facts.

If a skipped check affects a locked fact, the plan remains blocked.

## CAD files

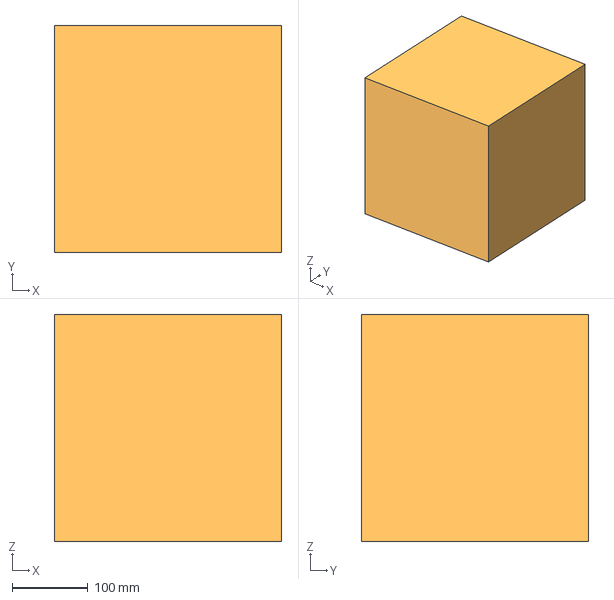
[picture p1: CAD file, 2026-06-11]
viewer/public/samples/simple-cube.step
300.0 x 300.0 x 300.0 mm

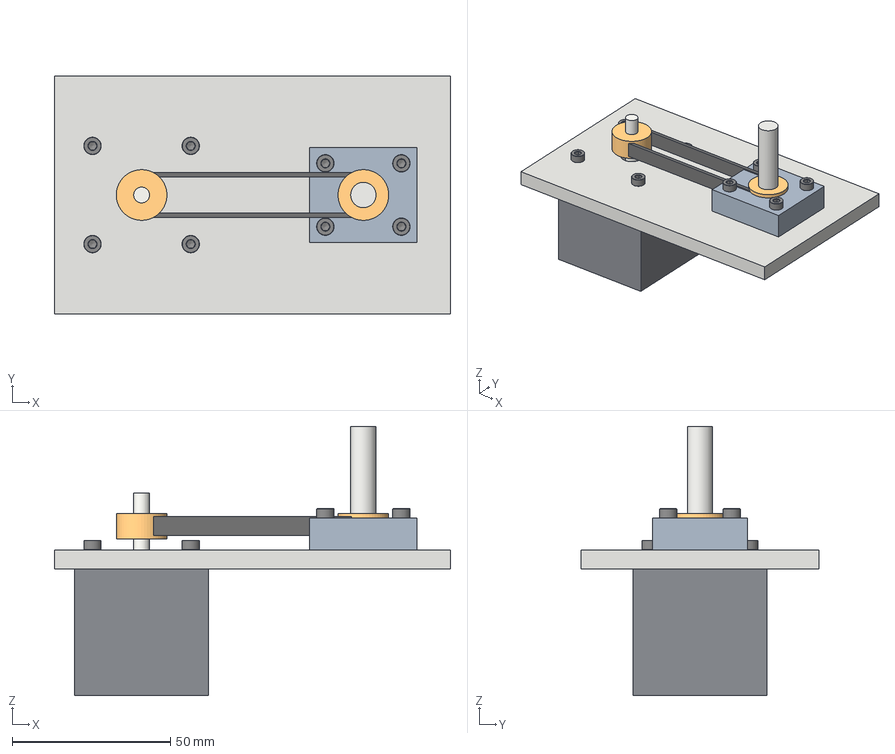
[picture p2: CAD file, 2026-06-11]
work/compact_belt_drive_module/review/step/compact_belt_drive_module_layout.step
125.0 x 75.0 x 85.0 mm
base_plate
nema17_motor_body
nema17_front_boss
motor_shaft_axis_5mm
bearing_support_block
source_locked_bearing_608zz
output_shaft_axis_8mm
motor_gt2_20t_5mm_pulley_body
motor_gt2_20t_5mm_pulley_pitch_plane_marker
output_gt2_20t_8mm_pulley_body
output_gt2_20t_8mm_pulley_pitch_plane_marker
gt2_belt_top_span
gt2_belt_bottom_span
gt2_belt_motor_wrap
gt2_belt_output_wrap
source_locked_motor_m3x10_fastener_1
source_locked_motor_m3x10_fastener_2
source_locked_motor_m3x10_fastener_3
source_locked_motor_m3x10_fastener_4
source_locked_support_m3x12_fastener_1
source_locked_support_m3x12_fastener_2
source_locked_support_m3x12_fastener_3
source_locked_support_m3x12_fastener_4

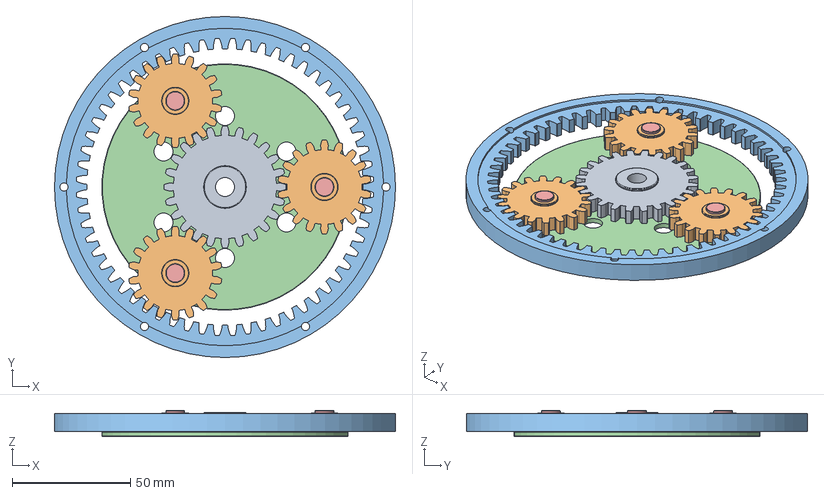
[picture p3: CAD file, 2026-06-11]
work/flat_planetary_gear_assembly/review/source/layout_proxy_build123d.step
144.0 x 144.0 x 11.0 mm
sun_gear
planet_gear_1
planet_gear_2
planet_gear_3
ring_gear
carrier
pin_1
pin_2
pin_3

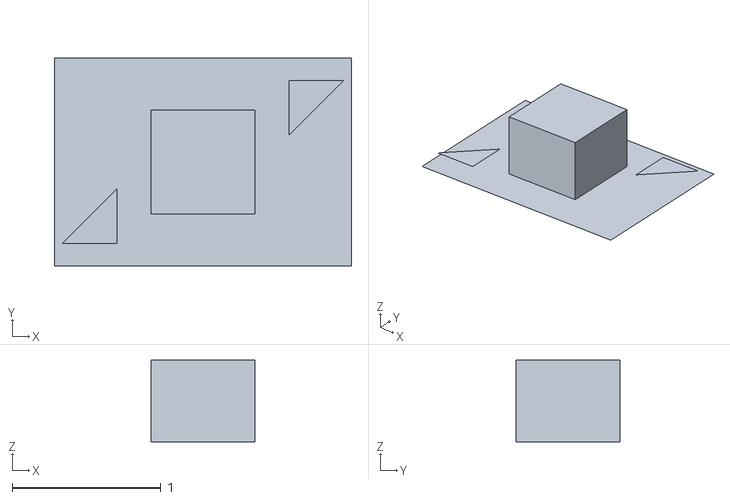
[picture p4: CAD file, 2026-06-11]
viewer/public/samples/generated-bracket.stl
2.00 x 1.40 x 0.55

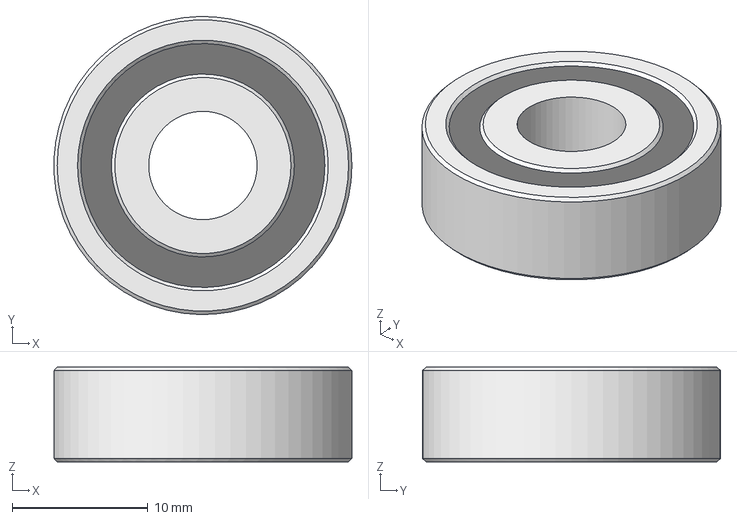
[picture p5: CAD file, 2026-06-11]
work/compact_belt_drive_module/sourced_parts/step_parts/bearing_608zz.step
22.0 x 22.0 x 7.00 mm

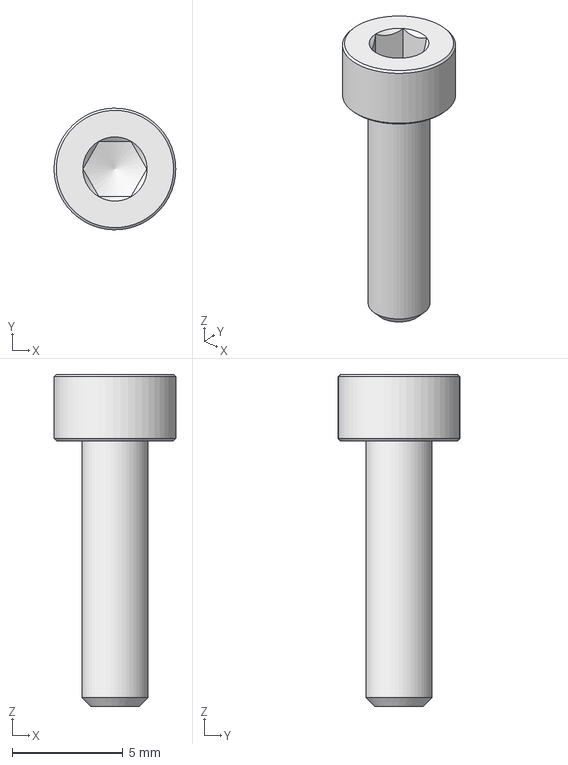
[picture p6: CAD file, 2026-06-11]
work/compact_belt_drive_module/sourced_parts/step_parts/iso4762_socket_head_cap_screw_m3x12.step
5.49 x 5.50 x 15.0 mm

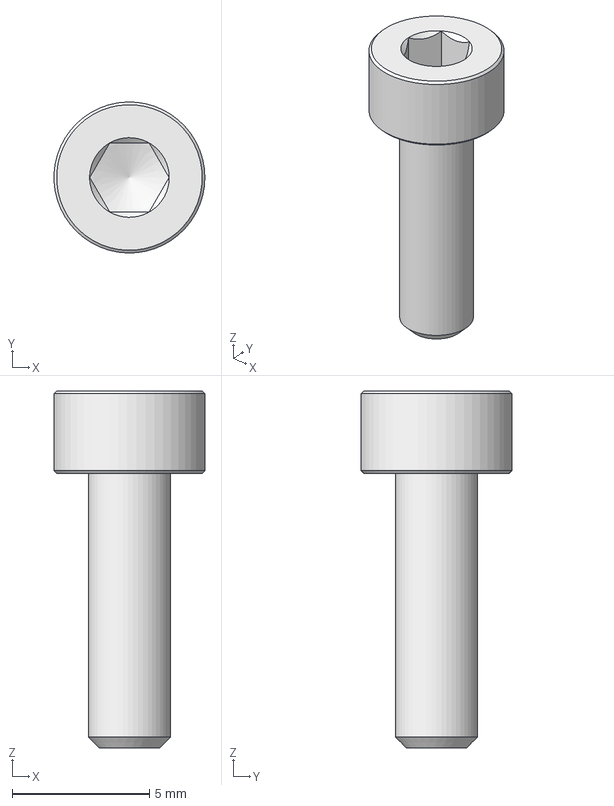
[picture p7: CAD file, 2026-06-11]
work/compact_belt_drive_module/sourced_parts/step_parts/iso4762_socket_head_cap_screw_m3x10.step
5.49 x 5.50 x 13.0 mm

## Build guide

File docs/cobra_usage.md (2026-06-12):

# CoBrA Usage

Zen CAD can be installed into CoBrA as workspace skills. The installer copies the core Zen CAD skill pack into the local CoBrA workspace, writes a `ZEN_CAD_WORKSPACE.md` binding beside each installed skill, and optionally prepares a repo-local Python virtualenv for build123d STEP generation.

## Quickstart

```bash
git clone https://github.com/songch9511/zen-cad.git
cd zen-cad
python3 tools/install_cobra.py --with-cad-deps
```

After installation, start a new CoBrA chat or refresh the skill picker. Use:

```text
/zen-cad create a NEMA17 mount plate
```

or route directly:

```text
/cad-spec create a GT2 belt driven linear slide
```

## What Gets Installed

The installer writes these workspace skills:

- `/zen-cad`
- `/cad-spec`
- `/assembly-layout`
- `/interface-signatures`
- `/cad-handoff`
- `/cad-replacement`
- `/constrained-detail-cad`

By default, the target directory is:

```text
~/.cobra/workspace/skills
```

Existing installed Zen CAD skill directories are backed up under:

```text
~/.cobra/backups/zen-cad-skill-install-<timestamp>
```

## Spec-Only Install

If you only want the skills and contract workflow, skip CAD dependencies:

```bash
python3 tools/install_cobra.py
```

This is enough for spec, layout, replacement planning, constrained detail planning, and downstream handoff prompts. Local build123d STEP generation requires `--with-cad-deps`.

## Custom Paths

Use a separate CoBrA home or skills directory when testing:

```bash
python3 tools/install_cobra.py --cobra-home /tmp/cobra-home
python3 tools/install_cobra.py --skills-dir /tmp/cobra-home/workspace/skills
```

Use a specific Python for CAD dependencies:

```bash
python3 tools/install_cobra.py --with-cad-deps --python /opt/homebrew/bin/python3.11
```

Preview changes without writing:

```bash
python3 tools/install_cobra.py --dry-run
```

## Verification

The installer runs the contract validator unless `--skip-validate` is passed. For a full local check after installing CAD dependencies:

```bash
.venv/bin/python tools/validate_contract.py
.venv/bin/python -m unittest discover -s tests
```

For build123d generation from an existing contract package:

```bash
.venv/bin/python tools/run_contract_pipeline.py --package <contract-package> --out <run-dir> --target-harness build123d
```

## Troubleshooting

If CoBrA does not show the skills, refresh the skill picker or start a new chat. CoBrA scans `~/.cobra/workspace/skills/<slug>/SKILL.md`.

If local generation reports `build123d import failed`, run:

```bash
python3 tools/install_cobra.py --with-cad-deps
```

If a skill resolves repo paths incorrectly, open the installed skill directory and check `ZEN_CAD_WORKSPACE.md`. Its `Repository root:` line should point to this Zen CAD checkout.

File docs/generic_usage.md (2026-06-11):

# Generic Usage

Zen CAD 1.1 can be used in any agentic environment that can read Markdown and hand work to a CAD-generation toolchain. The product version is 1.1.0, while contract documents continue to use `schema_version: 0.8.0` for compatibility.

Start with:

```text
Use skills/cad-spec/SKILL.md to write a CAD-native spec for: <goal>
```

When installed as a Codex plugin, use `/cad-spec` directly. Project connection alone does not
register slash skills; install the local `zen-cad` plugin from `.codex-plugin/marketplace.json`
and start a new chat after installation.

If the user asks to continue into CAD generation, keep `cad-spec` as the lead workflow and delegate bounded specialist tasks when the harness supports subagents:

- layout contract review;
- parameter contract review;
- interface signature extraction;
- motion and drivetrain relationship checks;
- layout proxy generation;
- interface-frame contract generation;
- source/detail replacement planning;
- constrained detail shape planning;
- generated artifact inspection;
- repair-loop review;
- generated CAD review against locked facts.

For generated CAD review, ask the lead agent to create a Subagent Dispatch Plan before editing geometry. The minimum useful review roles are `visual-reviewer`, `engineering-reviewer`, and `cad-reviewer`. If the active harness cannot spawn subagents, the lead should state the fallback and run those roles sequentially instead of silently doing everything in the lead session.

Use `skills/cad-handoff/SKILL.md` when the active generator needs a concise task brief. If the active target is build123d and local dependencies are available, Zen CAD can generate a first-pass STEP artifact itself before the proceed review. Contract packages can include `cad_spec.extensions.cad_feature_plan` when native generation should preserve holes, bores, repeated hole patterns, rectangular top chamfers, simplified gear teeth, or supported cylinder edge-round approximations.

Use `skills/cad-replacement/SKILL.md` when a layout proxy should be replaced by source-locked STEP/STP, user-provided detail CAD, or a generated detail candidate. The replacement must map proxy interface frames to source/detail frames and inspect locked facts after transformation.

Use `skills/constrained-detail-cad/SKILL.md` when a custom part should take on a user-requested shape while preserving locked facts. The detail shape plan should split protected interface zones from functional structure and freeform/style zones before CAD generation.

Use `schemas/` when a harness needs machine-readable contracts, and use `registry/interfaces/` when a layout proxy needs known component interface facts without catalog crawling. For final-stage standard/catalog part sourcing, use `schemas/source_lock_evidence.schema.json` and `tools/generate_source_lock_evidence.py` to record explicit step.parts, manufacturer, datasheet, project-file, or user-provided evidence separately from layout interface signatures. Use `tools/download_step_part.py` when a step.parts match should be downloaded, sha256-verified, and written as local source-lock evidence. When that evidence includes a STEP/STP geometry reference, `tools/export_cad_source.py` imports the sourced part into generated build123d source and removes the matching proxy primitives.

For 1.1 replacement/detail workflows, use `schemas/interface_frame.schema.json` for proxy/source/detail frame anchors, `schemas/replacement_plan.schema.json` for replacement transforms and required checks, and `schemas/detail_shape_plan.schema.json` for custom detail CAD intent, protected zones, and inspection gates.

Run the contract pipeline runner after a contract package exists. Use `--target-harness build123d` when Zen CAD should execute the generated source and write a STEP artifact locally:

```bash
python3 tools/run_contract_pipeline.py --package <path> --out <dir> --target-harness build123d
```

The runner verifies the built-in schema and registry surface, validates the package, creates a kernel-neutral `layout_proxy.scene.json`, inspects scene carry-through, exports CAD source intent, imports source-locked STEP/STP parts when geometry references exist, inspects source carry-through, executes generated build123d source into a primary STEP artifact when the target is `build123d`, packages a local viewer link, optionally captures a viewer PNG snapshot, packages proceed review, and writes a machine-readable `review_bundle.json`.

Imported source geometry is not enough by itself. If source/detail geometry replaces a proxy, the proceed package should include replacement frame mapping and post-replacement inspection of axes, planes, bolt patterns, clearances, and relationships before claiming the locked layout survived.

Visual review should look for floating bodies, unintended interference, insufficient clearance, missing fastener engagement, shaft/bore or bearing misalignment, belt/gear mesh errors, and implausible support or load paths. Treat those findings as repair leads: add or name a measurable check, repair the smallest source-level cause, regenerate, and recapture the relevant view.

To make the viewer link auto-load in the repo-local viewer, run the viewer on `http://localhost:5173`. When `viewer/public` exists, the runner uses it automatically:

```bash
(cd viewer && npm run dev:local)
python3 tools/run_contract_pipeline.py --package <path> --out <dir> --target-harness build123d --viewer-base-url http://localhost:5173
```

To also capture a review snapshot through the repo-local viewer, install viewer dependencies and enable capture:

```bash
npm --prefix viewer install
python3 tools/run_contract_pipeline.py --package <path> --out <dir> --target-harness build123d --viewer-base-url http://localhost:5173 --capture-viewer-snapshot
```

The build123d generation phase can also be run directly:

```bash
python3 tools/generate_cad_artifact.py --source <dir>/source/layout_proxy_build123d.py --manifest <dir>/source/cad_source_manifest.json
```

This performs source import, `gen_step()`, STEP export, STEP re-import, validity, bounding-box, and volume checks. It is still a first-pass CAD artifact, not manufacturing certification.

Native benchmark packages are available under `benchmarks/` for regression and prompt calibration:

- `benchmarks/01-rectangular-calibration-block/package`;
- `benchmarks/02-circular-flange/package`;
- `benchmarks/03-planetary-gear-stage/package`.

For a viewer-oriented downstream review, package the proceed gate into a Markdown brief:

```bash
python3 tools/package_viewer_review.py --proceed-gate <dir>/proceed_gate.json --pipeline-run <dir>/pipeline_run.json --out <dir>/viewer_review.md
```

Add `--viewer-artifact <path>` for saved screenshots, viewer pages, GLB/STL/3MF models, or viewer-side reports. The brief treats those files as review aids only; completion evidence still comes from the proceed gate status, inspection reports, locked facts, and downstream geometry measurements.

After the user approves the layout, record the decision and run the detail handoff stage:

```bash
python3 tools/approve_proceed_gate.py --proceed-gate <dir>/proceed_gate.json --out <approval.json>
python3 tools/run_contract_pipeline.py --package <path> --out <detail-dir> --target-harness text-to-cad --approval <approval.json>
python3 tools/package_text_to_cad_bundle.py --handoff <detail-dir>/detail_handoff.json --out <text-to-cad-bundle-dir>
```

For CAD Skills/text-to-cad, the bundle contains `text_to_cad_prompt.md`, `handoff_packet.json`, and `adapter_manifest.json`. The bundle is a downstream contract and prompt only; CAD source, STEP export, geometry checks, snapshots, and viewer links remain text-to-cad responsibilities.

The phase tools remain available for focused diagnosis:

- `tools/validate_contract.py`;
- `tools/generate_layout_proxy.py`;
- `tools/inspect_layout_proxy.py`;
- `tools/export_cad_source.py`;
- `tools/inspect_cad_source.py`;
- `tools/generate_cad_artifact.py`;
- `tools/package_viewer_link.py`;
- `tools/capture_viewer_snapshot.py`;
- `tools/package_proceed_gate.py`;
- `tools/package_review_bundle.py`;
- `tools/package_viewer_review.py`;
- `tools/approve_proceed_gate.py`;
- `tools/generate_detail_handoff.py`;
- `tools/package_text_to_cad_bundle.py`;
- `tools/generate_source_lock_evidence.py`;
- `tools/download_step_part.py`;
- `schemas/interface_frame.schema.json`;
- `schemas/replacement_plan.schema.json`;
- `schemas/detail_shape_plan.schema.json`.

These tools keep the contract layer explicit while adding a build123d generation path. They do not replace advanced topology inspection, source-locked supplier geometry alignment checks, manufacturing review, or engineering certification. Viewer links and snapshots are review aids only.

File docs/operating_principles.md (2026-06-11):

# Operating Principles

- Start with `/cad-spec`.
- Spec the assembly contract before generating CAD.
- Name parameters, artifact targets, inspection checks, and repair rules before handoff.
- Use low-detail layout proxies for first-pass positioning.
- Treat layout proxies as precise interface scaffolds, not visual placeholders.
- Preserve interface primitives, datums, axes, center distances, and drivetrain relationships before surface fidelity.
- Use interface signatures when layout needs standard component facts but full supplier geometry is unavailable.
- Use specialist subagents for bounded CAD subtasks when the harness supports delegation.
- For generated CAD, create a Subagent Dispatch Plan before editing geometry; if subagents are unavailable, state the sequential fallback explicitly.
- Use visual review to find likely fastening, clearance, floating body, interference, mesh/alignment, and engineering plausibility problems, then convert each concern into a measurable check.
- Repair generated CAD by changing the smallest responsible source-level cause, then rerun the failed checks.
- Do not validate CAD by git diff, file size, screenshot, or viewer link alone.
- Use built-in interface registry facts for layout when available; record misses and use documented envelopes instead of broad catalog crawling.
- Keep contract documents on `schema_version: 0.8.0` until the compatibility contract changes.
- Validate machine-readable contract packages before treating them as generator-ready.
- Prefer the one-command kernel-neutral contract pipeline runner for standard package processing.
- Generate kernel-neutral layout proxy scenes before adding CAD-kernel-specific exporters.
- Inspect layout proxy scenes against locked facts before treating them as ready for CAD export.
- Export CAD source through an adapter, then inspect source-level carry-through before user proceed review.
- Replace proxies with source/detail CAD only through interface-frame mapping and post-replacement locked-fact inspection.
- Generate custom detail CAD from protected interface zones plus user shape intent; locked facts stay hard, shape intent stays soft.
- When the target is build123d and dependencies are available, execute generated source into a STEP artifact and record export/import/bbox/volume checks before proceed review.
- Use `cad_feature_plan` for native holes, bores, repeated patterns, rectangular top chamfers, simplified gears, and supported cylinder edge-round approximations when prose alone is too ambiguous.
- Package local viewer links for generated STEP artifacts when a viewer is available, but keep them below geometry checks in evidentiary strength.
- Package proceed gates before asking for approval.
- Generate detail-upgrade handoffs only from an explicit proceed approval artifact.
- Treat proceed approval as a lock on layout facts.
- Return to the proceed gate if replacement or constrained detail generation requires changing an approved frame, axis, pattern, clearance, or relationship.
- Do not claim engineering certification from CAD geometry alone.

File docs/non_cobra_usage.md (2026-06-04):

# Non-CoBrA Usage

Zen CAD 0.8 can be used in any agentic environment that can read Markdown and hand work to a CAD-generation toolchain.

## Codex, Claude Code, Cursor, Or Similar

Open this repository as the workspace and start with:

```text
Use skills/cad-spec/SKILL.md to write a CAD-native spec for: <goal>
```

Then hand the spec to the active CAD generator:

```text
Use skills/cad-handoff/SKILL.md to brief the active CAD harness for a low-detail layout proxy.
```

Use `skills/assembly-layout/SKILL.md` when reviewing positioning, contacts, connections, motion relationships, or proceed readiness. Use `skills/interface-signatures/SKILL.md` when a layout needs standard component interface facts before full sourced STEP geometry exists.

## Legacy CLI

The repo-local `./zen-cad` CLI remains available for legacy milestone experiments:

```bash
./zen-cad doctor
./zen-cad new "<goal>"
./zen-cad validate --level structure milestones/<id>
```

Use completion gates only when working on legacy final-evidence packaging.

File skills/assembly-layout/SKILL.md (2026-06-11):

---
name: assembly-layout
description: Define and review low-detail mechanical assembly layouts before detail CAD. Use for assembly graphs, root frames, contact/connection concepts, locked interface facts, positioning review, drivetrain layout review, and proceed-gate readiness.
version: 1.0.2
---

# Assembly Layout

## Purpose

Use this skill to define or review the low-detail assembly contract that should be correct before detail CAD begins. It is narrower than `cad-spec`: it focuses only on how parts locate, mate, move, clear, and connect.

This skill does not generate CAD, source parts, or replace the lead CAD spec.

## Use This Skill When

Use it when a task needs:

- assembly graph definition;
- root frame and part-local frame decisions;
- contacts, connections, joints, clearances, keep-outs, or motion limits;
- proceed review after a layout proxy;
- source-level positioning, measurement, frame, or mate-check expectations;
- drift checks between approved layout and detail CAD.

## Workflow

1. Identify the fixed/root component.
2. Define root frame and part-local frames.
3. List each part's role: structure, locator, driver, driven, guide, fastener, cover, sensor, proxy.
4. Define contacts and connections as relationships, not file-format rows.
5. Name locked facts that detail CAD must preserve.
6. Define measurement, frame, mate, or snapshot checks that can prove positioning.
7. Define the proceed review checklist.
8. If reviewing a generated layout, compare it only against the locked facts and layout intent.

## Relationship Types

Use clear relationship names:

- `contacts`: faces, cylinders, pitch references, keep-out boundaries, or clearance pairs.
- `connections`: fasteners, press fits, bearings, shafts, hinges, belts, gears, rails, sliders, couplers, cables.
- `motion`: revolute, prismatic, cylindrical, belt-coupled, gear-coupled, screw-driven, linkage-driven.

## Non-Negotiables

- Do not approve detail modeling if the assembly graph is still unclear.
- Do not treat a pretty surface as evidence that a mate or drivetrain is correct.
- Do not rely on visual placement alone when a distance, axis, frame, or mating check can be named.
- Do not change locked facts during detail upgrade without returning to layout review.
- Do not require supplier STEP files for layout review when interface signatures are sufficient.

## References

- `references/layout-contract.md` — assembly graph, contact, connection, and locked fact shape.
- `references/review-checklist.md` — proceed review checklist and layout drift checks.

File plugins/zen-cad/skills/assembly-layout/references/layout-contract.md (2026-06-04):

# Layout Contract

A layout contract describes how an assembly is organized before detail geometry is generated.

## Required Items

- root component;
- root frame;
- part list with roles;
- part-local frames;
- contact relationships;
- connection relationships;
- motion relationships;
- clearance and keep-out envelopes;
- inspection targets for positioning facts;
- locked facts;
- proxy parts and their trustworthy interfaces.

## Contact Relationship

Use contacts for geometry adjacency or clearance:

```text
contact: motor_face_to_plate
- part_a: motor_proxy
- part_b: mount_plate
- relationship: flush_plane
- expected_gap_mm: 0
- locked: true
```

## Connection Relationship

Use connections for attachment or power/motion transfer:

```text
connection: pulley_to_motor_shaft
- type: coaxial_clamp
- shaft_axis: motor_shaft_axis
- bore_diameter_mm: 5
- locked: true
```

## Locked Facts

Locked facts should be stable enough to drive detail modeling:

- axis directions;
- center distances;
- part transforms;
- mounting pattern coordinates;
- pitch references;
- clearances;
- travel limits;
- fixed/moving hierarchy.

## Inspection Targets

For every positioning-sensitive locked fact, name at least one check the downstream generator can run or report:

- bounding box for footprint and height;
- distance or center-distance measurement;
- coaxial, flush, centered, or parallel mate check;
- world frame for a moving child, fastener pattern, rail, or shaft;
- plane or axis presence for mounting faces, bores, slots, and pitch references;
- snapshot or viewer review for visible layout semantics when supported.

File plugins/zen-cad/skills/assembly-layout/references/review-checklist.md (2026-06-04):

# Review Checklist

Use this checklist before allowing detail CAD to proceed from a layout proxy.

## User Review

Ask the user to inspect:

- Does the fixed/root component make sense?
- Are moving axes oriented correctly?
- Are center distances and offsets plausible?
- Do shafts, bores, bearings, and pulleys share the intended axes?
- Are belt, gear, rail, screw, or linkage relationships positioned correctly?
- Are mounting faces and bolt patterns on the intended sides?
- Are clearance and keep-out envelopes visible and plausible?
- Are proxies acceptable for this stage?

## Generator Evidence

Ask the generator or reviewer to return:

- source-level placement method: joints, transforms, constraints, or explicit coordinates;
- generated artifact path;
- bounding box and top-level labels;
- checks for locked distances, axes, frames, or mating relationships;
- snapshot or viewer link when supported;
- failed or skipped checks with reasons.

## Detail May Change

Detail modeling may change:

- surface smoothness;
- fillets and chamfers;
- thread representation;
- tooth fidelity;
- supplier body contours;
- labels;
- export formats.

## Detail Must Not Change

Detail modeling must not change:

- root frame;
- assembly graph;
- fixed/moving hierarchy;
- axes;
- center distances;
- part transforms;
- pitch references;
- mounting faces;
- bolt patterns;
- clearances;
- travel ranges.

If any protected item must change, return to layout review.

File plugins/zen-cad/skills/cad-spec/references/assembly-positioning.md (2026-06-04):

# Assembly Positioning

Read this when a design has more than one part, mating geometry, repeated features, motion, or user-visible layout risk.

## Core Rule

Positioning is a source-level design fact, not a visual afterthought. A downstream CAD generator may use build123d joints, explicit transforms, mates, constraints, or another mechanism, but the spec must define the intended frames and relationships before geometry is generated.

## Required Positioning Facts

For each assembly:

- fixed/root component;
- root frame origin and axes;
- part-local frame convention for each positioned part;
- primary datum faces, axes, and centerlines;
- intended contacts, clearances, and offsets;
- moving joints and allowed degrees of freedom;
- repeated component pattern origins and spacing;
- world-frame expectations for critical parts.

## Preferred Relationship Types

Use precise relationship names:

- `flush_plane`: two planes touch with zero or named gap.
- `coaxial`: two cylinders or axes share a centerline.
- `parallel_axes`: axes remain parallel with named offset.
- `centered_on`: one frame or feature is centered on another.
- `pitch_contact`: belt, gear, chain, or sprocket pitch references are tangent/meshed.
- `sliding_on`: carriage, rail, slot, or guide contact with travel range.
- `rotates_about`: shaft, hinge, bearing, or pulley rotation axis.
- `fastened_by`: screw, bolt, pin, insert, clamp, or press fit pattern.

## Locked Layout Facts

Lock only facts that must survive detail modeling:

- root frame;
- part transforms;
- datum frames;
- joint axes;
- center distances;
- pitch references;
- mounting faces;
- bolt patterns;
- bores and shaft diameters;
- rail/slot alignment;
- clearances and keep-outs;
- motion limits.

Do not lock cosmetic fillets, chamfers, tessellation quality, thread detail, tooth surface fidelity, or enclosure curvature unless they control an interface.

## Layout Drift

If detail modeling changes a locked fact, do not patch forward silently. Return to the proceed gate and ask for layout re-approval.

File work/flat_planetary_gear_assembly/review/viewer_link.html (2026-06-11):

# layout_proxy_build123d.step

Open in CAD Viewer (http://localhost:5173/?label=layout_proxy_build123d.step&realCanvas=1)

Mode: auto_load

Generated STEP: work/flat_planetary_gear_assembly/review/source/layout_proxy_build123d.step

Served STEP: /Users/daniel/CAD-Visualizer/public/zen-cad-artifacts/layout_proxy_build123d-703d2a079d.step

This link is review evidence only. Geometry checks and inspection reports remain the completion evidence.

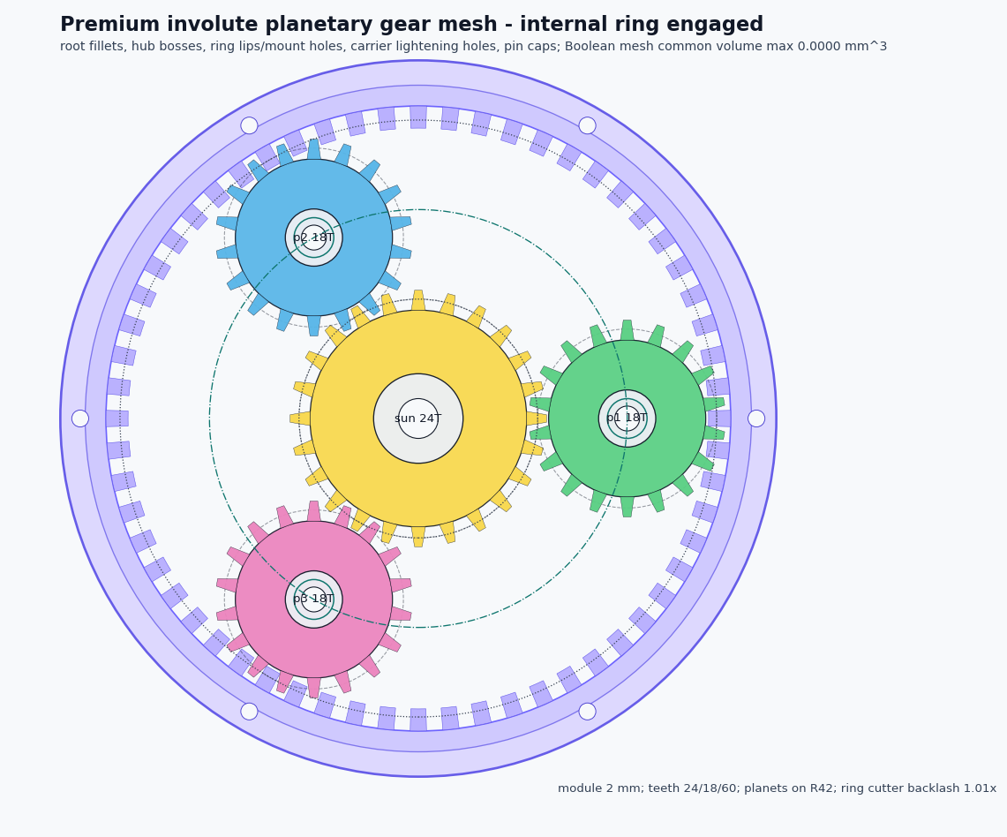
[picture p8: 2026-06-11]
work/flat_planetary_gear_assembly/review/layout_snapshot.png

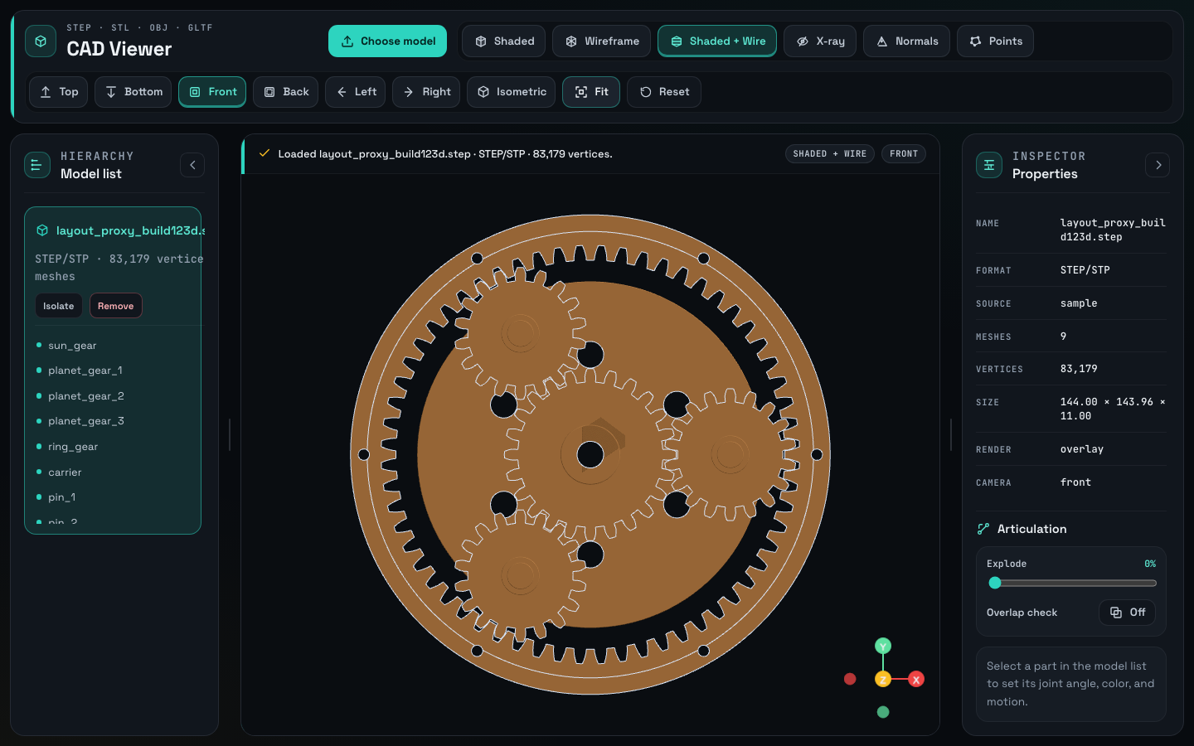
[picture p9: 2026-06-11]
work/flat_planetary_gear_assembly/review/viewer_snapshot.png

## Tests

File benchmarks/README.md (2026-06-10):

# Zen CAD Native Benchmarks

These benchmarks adapt three CADSkills-style prompts into Zen CAD native contract packages. Each package is meant to run through the local contract pipeline and produce a build123d STEP artifact plus proceed-gate review evidence.

Run one benchmark:

```bash
python3 tools/run_contract_pipeline.py \
  --package benchmarks/01-rectangular-calibration-block/package \
  --out /tmp/zen-cad-rectangular-block \
  --target-harness build123d
```

For a CAD-Visualizer auto-load link, pass the viewer public directory:

```bash
python3 tools/run_contract_pipeline.py \
  --package benchmarks/02-circular-flange/package \
  --out /tmp/zen-cad-flange \
  --target-harness build123d \
  --viewer-base-url http://localhost:5173 \
  --viewer-public-dir /Users/daniel/CAD-Visualizer/public
```

## Targets

| # | Benchmark | Prompt |
|---|---|---|
| 1 | [Rectangular calibration block](01-rectangular-calibration-block/README.md) | Create a centered 100 x 60 x 20 mm block with four 8 mm vertical through-holes. Add only a 2 mm chamfer on the top outer perimeter. |
| 2 | [Circular flange](02-circular-flange/README.md) | Create an 80 mm diameter, 10 mm thick circular flange with a 30 mm central through-bore. Add six 6 mm through-holes on a 60 mm bolt circle and fillet the outside circular edges. |
| 3 | [Simplified planetary gear stage](03-planetary-gear-stage/README.md) | Create a flat planetary gear assembly with separate sun, planet, ring, carrier, and pin bodies. Use simplified trapezoidal teeth and place three planets around the sun on a 42 mm radius circle. |

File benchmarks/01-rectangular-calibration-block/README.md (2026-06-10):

# Rectangular Calibration Block

CADSkills-style prompt:

> Create a centered 100 x 60 x 20 mm block with four 8 mm vertical through-holes. Add only a 2 mm chamfer on the top outer perimeter.

Zen CAD native package:

```bash
python3 tools/run_contract_pipeline.py \
  --package benchmarks/01-rectangular-calibration-block/package \
  --out /tmp/zen-cad-rectangular-block \
  --target-harness build123d
```

Feature coverage:

- box base body;
- four vertical through-holes from explicit XY positions;
- top outer perimeter chamfer using lofted tapered geometry;
- STEP export, re-import, bbox, volume, and viewer-link packaging.

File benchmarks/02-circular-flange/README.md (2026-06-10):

# Circular Flange

CADSkills-style prompt:

> Create an 80 mm diameter, 10 mm thick circular flange with a 30 mm central through-bore. Add six 6 mm through-holes on a 60 mm bolt circle and fillet the outside circular edges.

Zen CAD native package:

```bash
python3 tools/run_contract_pipeline.py \
  --package benchmarks/02-circular-flange/package \
  --out /tmp/zen-cad-flange \
  --target-harness build123d
```

Feature coverage:

- cylindrical flange base;
- central through-bore;
- six-hole bolt circle pattern;
- outside circular edge fillet approximation using torus geometry;
- STEP export, re-import, bbox, volume, and viewer-link packaging.

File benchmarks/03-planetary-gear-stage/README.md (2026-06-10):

# Simplified Planetary Gear Stage

CADSkills-style prompt:

> Create a flat planetary gear assembly with separate sun, planet, ring, carrier, and pin bodies. Use simplified trapezoidal teeth and place three planets around the sun on a 42 mm radius circle.

Zen CAD native package:

```bash
python3 tools/run_contract_pipeline.py \
  --package benchmarks/03-planetary-gear-stage/package \
  --out /tmp/zen-cad-planetary \
  --target-harness build123d
```

Feature coverage:

- separate sun, planet, ring, carrier, and pin bodies;
- radial tooth-block patterns for sun and planets;
- internal tooth-slot pattern for the ring gear;
- three planets and three pins on a locked 42 mm radius circle;
- STEP export, re-import, bbox, volume, and viewer-link packaging.

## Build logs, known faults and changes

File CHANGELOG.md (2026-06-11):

# Changelog

## Unreleased

## 1.1.0 - 2026-06-11

- Add `cad-replacement` guidance for replacing layout proxies with source-locked STEP/STP or detail CAD while preserving interface frames, datums, axes, bolt patterns, clearances, and locked layout facts.
- Add `constrained-detail-cad` guidance for generating custom detail CAD from locked facts plus user shape intent, protected zones, manufacturing assumptions, and post-generation inspection.
- Add contract schemas for `interface_frame`, `replacement_plan`, and `detail_shape_plan` artifacts so agents can express replacement and custom generation work without relying on prose-only instructions.
- Update the plugin and documentation to position layout proxies as precise interface scaffolds for source replacement and constrained detail generation, not merely rough visual placeholders.

## 1.0.2 - 2026-06-11

- Add visual inspection and repair guidance for generated CAD review, including floating bodies, interference, clearance, fastening, alignment, mesh/contact, and support-path checks.
- Update `cad-spec` and `cad-handoff` workflows so agents ask for a Subagent Dispatch Plan when subagents are available, while using an explicit sequential fallback when they are not.
- Keep subagent orchestration as skill guidance only; do not add runtime/tool exposure that physically forces subagent spawning.
- Clean up the README around scope, usage, command flow, benchmarks, and the visual review boundary.

## 1.0.1 - 2026-06-10

- Add `tools/generate_cad_artifact.py` to execute generated build123d source, export a primary STEP artifact, re-import it, and record export/import/bbox/volume checks.
- Extend the contract pipeline so `--target-harness build123d` produces a generated STEP artifact and CAD generation inspection report before proceed review.
- Update docs and skills so Zen CAD is no longer framed as contract-only when a local build123d generation path is available.
- Add feature-plan carry-through for holes, bores, bolt-circle/repeated patterns, rectangular top chamfers, simplified gear teeth, and supported cylinder edge-round approximations.
- Add native benchmark contract packages for a rectangular calibration block, circular flange, and simplified planetary gear stage.
- Add `tools/package_viewer_link.py` and runner integration so generated STEP artifacts can enter proceed review with a local CAD Viewer link.
- Add `tools/capture_viewer_snapshot.py` and runner `--capture-viewer-snapshot` support so proceed gates can include PNG viewer evidence.
- Add `tools/download_step_part.py` for `api.step.parts` search/download, sha256 verification, and checksum-backed source-lock evidence.
- Tighten source-lock validation so checksum-recorded STEP/STP evidence requires a 64-hex sha256, and prefer local verified STEP copies over remote STEP URLs during source export.

## 1.0.0

- Add a dependency-free CAD Viewer review brief packager that turns proceed-gate and optional pipeline/viewer artifacts into a downstream review handoff.
- Make the viewer handoff explicit that screenshots, snapshots, and viewer links are review aids, not completion evidence.
- Add runner-backed tests for the viewer review brief and document the command flow.
- Add a CAD Skills/text-to-cad prompt bundle packager that accepts approved detail handoffs without generating CAD itself.
- Add machine-readable `source_lock_evidence` for final-stage standard/catalog part source evidence while keeping layout interface signatures layout-only.
- Add a dependency-free `tools/generate_source_lock_evidence.py` generator for explicit step.parts, manufacturer, datasheet, project-file, and user-provided source locators without catalog crawling.
- Add source-lock validation rules that prevent layout-only evidence from becoming a source lock and keep rating/certification claims out of the artifact.
- Import source-locked STEP/STP geometry into generated build123d source and replace matching layout proxy primitives when geometry references are present.
- Document the source-lock boundary in the interface signature references.
- Keep contract documents on `schema_version: 0.8.0` for contract compatibility.

## 0.9.0

- Bump the product and core skill versions to 0.9.0.
- Add the 0.9.0 one-command kernel-neutral contract pipeline runner for validation, layout proxy generation, scene inspection, CAD source export, source inspection, and proceed packaging.
- Add explicit proceed approval artifacts before detail handoff generation.
- Document runner-first usage across README and generic usage docs while keeping the phase tools available for focused diagnosis.
- Keep contract documents on `schema_version: 0.8.0` for contract compatibility.

## 0.8.9

- Reset Zen CAD to a focused CAD-native skill pack.
- Keep only the spec-first skills: `/cad-spec`, `/assembly-layout`, `/interface-signatures`, and `/cad-handoff`.
- Add specialist subagent orchestration guidance to `/cad-spec`.
- Add parameter contract, export target, inspection, and repair-loop guidance inspired by text-to-cad workflows.
- Add machine-readable schema foundation for CAD specs, layout contracts, interface signatures, inspection reports, and handoff packets.
- Add a small layout-ready interface registry for common motors, belts, bearings, fasteners, shaft/bores, and rails.
- Add `tools/validate_contract.py` for dependency-free schema, registry, and contract-package validation.
- Add `tools/generate_layout_proxy.py` for dependency-free kernel-neutral layout proxy scene generation.
- Add `tools/inspect_layout_proxy.py` for dependency-free locked-facts inspection of layout proxy scenes.
- Add `tools/export_cad_source.py`, `tools/inspect_cad_source.py`, `tools/package_proceed_gate.py`, and `tools/generate_detail_handoff.py` to complete the 0.8.9 kernel-neutral handoff pipeline.
- Remove old workflow skills, workspace-specific CLI helpers, templates, checklists, prompts, plugins, fixtures, and release-package machinery from the main surface.

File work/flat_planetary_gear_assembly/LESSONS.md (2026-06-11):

# Lessons: Flat Planetary Gear Assembly

## What Failed

1. The first interpretation of "teeth must not overlap" was too shallow.
   - Failure: the model avoided tooth overlap by effectively separating or loosely aligning teeth.
   - Why it was wrong: in a planetary gear, teeth must intermesh into opposing tooth spaces while solid tooth volumes remain non-overlapping.
   - Lesson: "no overlap" is not the same as "no contact" or "visually separated."

2. The ring gear was not treated as a real internal gear at first.
   - Failure: the outside ring looked like a toothed ring, but the planets did not convincingly mesh with its internal teeth.
   - Why it was wrong: a planetary ring gear must satisfy the same module/pitch system as the sun and planets.
   - Correct relation used later: `Nr = Ns + 2Np`, with `Ns/Np/Nr = 24/18/60`, `module = 2 mm`, and planet center radius `42 mm`.

3. Simplified radial trapezoid teeth broke down at the internal ring mesh.
   - Failure: radial block teeth could be phased to work at one mesh line, but neighboring teeth caused flank interference around the internal ring.
   - Why it was wrong: internal gear meshing is not just radial slots; the flank geometry matters.
   - Lesson: for planetary gears, especially internal ring meshes, use involute geometry or a proven gear generator before claiming engineering plausibility.

4. Visual review was initially over-weighted.
   - Failure: screenshots made the layout look acceptable before the actual mesh geometry was sufficiently checked.
   - Correct approach: use Boolean common volume checks between every meshing pair.
   - Required checks: sun/planet for all three planets and planet/ring for all three planets.

5. The first "premium" pass risked being cosmetic only.
   - User correctly asked for fillets and more mature detail because the model still looked toy-like.
   - Improvement had to preserve mesh facts while adding non-mesh detail.

## What The User Asked To Correct

1. "톱니들이 겹치면 안됨."
   - Interpreted first as simple non-overlap.
   - Corrected meaning: teeth must mesh, but solid tooth bodies must not occupy the same volume.

2. "가장 큰 바깥 Gear랑도 잘 맞물려야지."
   - Required the ring gear to be treated as an internal gear, not a decorative outer toothed circle.

3. "Planetary Gear에 대해서 더 조사하고 생성할 수 없어?"
   - Required using planetary gear relationships instead of hand-tuned visual placement.

4. "fillet 등을 넣어서 좀 장난감스럽지 않게, 더 고급지게."
   - Required a detail pass: root fillets, hub bosses, ring lips, mount holes, carrier holes, and pin caps.

## What Improved

1. The gear train was rebuilt around planetary constraints.
   - `Ns = 24`
   - `Np = 18`
   - `Nr = 60`
   - `module = 2 mm`
   - `sun pitch radius = 24 mm`
   - `planet pitch radius = 18 mm`
   - `ring pitch radius = 60 mm`
   - `24 + 18 = 42`
   - `60 - 18 = 42`

2. The tooth geometry moved from trapezoid proxy to involute geometry.
   - Sun and planets use `bd_warehouse.gear.SpurGear`.
   - Ring gear is generated by subtracting a scaled 60T involute cutter from the ring blank.
   - Ring cutter scale `1.01x` provides static tooth-space clearance/backlash.

3. Mesh phase was validated, not guessed.
   - Sun rotation: `0 deg`
   - Planet rotations: `theta - 10 deg`
   - Ring slot phase: `-3 deg`
   - Result: all six meshing pairs have Boolean common volume `0.0`.

4. The final model gained premium non-mesh details.
   - `0.1 mm` tooth root fillets.
   - Raised sun and planet hub bosses.
   - Ring outer lips.
   - Six ring mount holes.
   - Carrier edge fillet and six lightening holes.
   - Filleted pin stems and caps.

5. The validation artifacts became more meaningful.
   - STEP generation report.
   - Supplemental geometry report.
   - Viewer snapshot.
   - Layout snapshot.
   - Proceed gate and review bundle.

## Rules For Next Time

1. Do not generate a planetary gear assembly from visual intuition alone.
   - First lock tooth counts, module, pitch radii, center distance, and planet spacing condition.

2. Do not use radial trapezoid teeth for an internal ring gear if the user expects engineering plausibility.
   - Trapezoid teeth are acceptable only as a clearly labeled rough visual proxy.
   - For internal ring mesh, use involute geometry or a negative cutter workflow.

3. Do not treat "teeth do not overlap" as "teeth are separated."
   - Correct criterion: teeth enter opposing tooth spaces while Boolean common volume remains zero.

4. Do not approve a ring gear by screenshot.
   - Must check planet/ring Boolean intersections for all planets.

5. Do not add fillets/details before mesh validation is stable.
   - Detail pass must be non-mesh and must not alter pitch radii, gear centers, tooth counts, or phase.

6. Do not let cosmetic improvements hide drivetrain errors.
   - Premium details are secondary to the locked gear mesh.

7. Do not claim production readiness from this STEP.
   - Static CAD validation is not torque, load, wear, lubrication, backlash dynamics, noise, or manufacturability certification.

## Reusable Checklist

- Confirm `Nr = Ns + 2Np`.
- Confirm `planet_radius = module * (Ns + Np) / 2`.
- Confirm `ring_pitch_radius - planet_pitch_radius = planet_radius`.
- Confirm equal planet spacing condition, e.g. `(Ns + Nr) / planet_count` is an integer for this sign convention.
- Use involute sun and planet teeth.
- Generate internal ring as a negative involute cutter or equivalent internal gear profile.
- Phase sun, planets, and ring slots.
- Check Boolean common volume for every sun/planet and planet/ring pair.
- Only then add fillets, hubs, lips, holes, caps, and other premium details.
- Re-run STEP import, bbox, volume, snapshot, and proceed gate packaging.

## Final Session Outcome

The final assembly uses module-locked involute gears with a negative-cutter internal ring, premium non-mesh details, and zero Boolean common volume across all six meshing pairs. It is ready for user review as a static CAD review model, not as a certified production gearset.

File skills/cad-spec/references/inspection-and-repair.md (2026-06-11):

# Inspection And Repair

Read this when CAD generation, review, or detail upgrade is requested.

## Principle

Generated CAD should be checked against the spec, not against visual plausibility alone. Programmatic facts, dimensions, planes, frames, mating deltas, and labels are stronger evidence than screenshots or viewer links. Visual snapshots are useful review aids and should be converted into geometry checks before becoming claims. Use `visual-inspection-and-repair.md` when the review needs multi-view snapshots, visible fit checks, or engineering plausibility repair.

## Inspection Plan

Before handoff, state what the downstream generator or reviewer should check:

- artifact exists and is generated from the intended source;
- top-level solids, parts, labels, and assembly children match the spec;
- bounding box, key dimensions, clearances, and center distances are within expected values;
- major planes, axes, bores, shafts, pitch references, and mounting faces are present;
- part-local frames and world placements preserve locked layout facts;
- motion poses, travel limits, gear or belt relationships, and keep-outs are plausible;
- visual snapshot or viewer review is included when the active tool supports it, or skipped with a reason.
- visual concerns for fastening, clearance, floating bodies, interference, mesh/alignment, and engineering plausibility are converted into measurable checks or explicit skipped risks.

## Inspection Hierarchy

Use the strongest available evidence in this order:

1. source-level parameters, datums, joints, and labels;
2. generated artifact facts such as solid counts, labels, bounding boxes, planes, and axes;
3. targeted measurements, mate checks, frame checks, or diffs;
4. visual snapshots or viewer links;
5. prose caveats for checks that could not run.

Do not report a check as passed unless it actually ran or is directly supported by generated source facts.
Do not validate CAD by git diff, file size, screenshot, or viewer link alone.

## Repair Loop

When a check fails:

1. read the failing output or reviewer finding;
2. classify the failure;
3. change the smallest responsible source, parameter, datum, joint, or handoff instruction;
4. regenerate the affected artifact;
5. rerun the failed check and any dependent checks;
6. report remaining risk or deliberate deviations.

Locked layout facts cannot be changed inside the repair loop. If a repair requires changing an approved axis, center distance, mounting face, clearance, or drivetrain relationship, stop and return to the proceed gate.

## Common Failure Classes

- source syntax or import failure;
- invalid, missing, open, or zero-volume geometry;
- wrong scale, unit mismatch, or radius/diameter confusion;
- missing feature, wrong boolean direction, or shallow through-cut;
- selector or label fragility after a topology change;
- positioning mismatch, inverted axis, wrong local datum, or stale transform;
- visual concern that needs a measurement or frame check;
- floating or unconstrained body that needs a contact, mate, fastening path, or locked relationship check;
- fastening, clearance, shaft/bore, bearing, belt, gear, or support concern that needs an engineering-rule check;
- missing viewer, snapshot, or export capability in the active harness.

## Review Report

Ask the downstream agent to return:

- source path and primary artifact path;
- generation status;
- inspection checks actually run;
- failed or skipped checks with reasons;
- snapshot or viewer link when supported;
- visual findings, measurable checks added, and before/after evidence for repair passes;
- whether the model is ready for proceed review, detail upgrade, or another repair pass.

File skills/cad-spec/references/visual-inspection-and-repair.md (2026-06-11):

# Visual Inspection And Repair

Read this when generated CAD exists, a viewer or screenshot tool is available, or the user asks the agent to inspect and repair fit, fastening, clearance, mesh, floating bodies, or engineering plausibility.

## Principle

Visual inspection is a discovery mechanism, not final proof. The agent should use screenshots, viewer links, and multi-view snapshots to find likely problems, then convert each concern into a measurable geometry, interface, clearance, mate, or engineering-rule check before claiming it is fixed.

## Required View Packet

For generated assemblies, request or capture enough evidence to inspect the model from more than one angle:

- isometric shaded + wire overview;
- top, front, and right orthographic views;
- close views of fasteners, bearings, shafts, bores, gear or belt meshes, and support brackets;
- section, xray, exploded, or isolated-part views when available and useful;
- before/after snapshots for repair passes.

If the viewer cannot produce a required view, record the view as skipped with a reason and preserve the remaining geometry checks.

## Visual Issue Taxonomy

Classify visual findings with stable issue types:

- `floating_unconstrained_body`: a part appears unsupported, detached, or missing a contact/fastening relationship.
- `unintended_interference`: two solids visibly overlap where no press fit, merge, or boolean union is intended.
- `insufficient_clearance`: visible gap is too small or too large for the stated shaft, bore, fastener, belt, gear, or enclosure relationship.
- `missing_fastener_engagement`: bolt, screw, boss, nut, washer, or mounting hole is absent, misaligned, too shallow, or not long enough to engage.
- `coaxiality_or_plane_misalignment`: shaft/bore axes, bearing seats, pulley planes, rail axes, or mounting datums are visibly off.
- `mesh_or_transmission_error`: gear teeth, belt centerline, pulley pitch plane, chain/sprocket, or linkage relationship is visibly implausible.
- `unsupported_or_implausible_load_path`: thin walls, overhangs, cantilevers, rib placement, or bracket support looks mechanically implausible for the stated role.
- `assembly_order_or_access_issue`: fasteners, shafts, covers, or service features cannot be inserted, removed, or reached in the shown layout.

## Finding Format

Each visual finding should include:

```text
issue_id:
issue_type:
view_or_artifact:
suspected_parts:
locked_fact_refs:
visual_evidence:
measurable_check_to_add:
smallest_repair_candidate:
stop_condition:
```

Use part ids and feature ids from the CAD spec, source, manifest, scene, or viewer hierarchy. Do not describe a repair only as "make it look better"; name the parameter, datum, placement, feature, mate, or clearance to change.

## Engineering Rule Checks

Prefer engineering-rule checks that can be measured or inspected from source:

- fastener axis aligns with hole axis and mounting faces;
- fastener length and boss depth are plausible for engagement;
- shaft diameter is compatible with bore diameter and clearance intent;
- bearing bore axis, shaft axis, and support bore are coaxial;
- pulley or gear pitch planes are coplanar where required;
- gear center distance matches pitch radii and intended mesh;
- belt centerline connects pulley pitch circles without a plane mismatch;
- moving parts have declared travel limits and keep-out clearance;
- body has a support/contact/fastening path back to the root frame;
- wall, rib, boss, and bracket dimensions are nonzero and plausible for layout.

Do not claim load rating, fatigue life, certification, or manufacturing readiness unless a downstream engineering analysis actually ran.

## Visual-To-Measurable Repair Loop

When visual inspection finds a concern:

1. classify the issue using the taxonomy;
2. identify the smallest source-level cause: parameter, placement, datum, feature, interface primitive, or handoff instruction;
3. add or rerun a measurable check that can fail before repair and pass after repair;
4. regenerate the affected CAD artifact;
5. recapture the same view packet or targeted close-up;
6. report before/after evidence, checks rerun, and remaining skipped risks.

If a repair would change a locked layout fact, stop and return to the proceed gate instead of silently adjusting the model.

## Subagent Pattern

For complex generated assemblies, dispatch at least these bounded review roles when subagents are available:

- `visual-reviewer`: inspect the view packet and return visual findings in the required format.
- `engineering-reviewer`: translate findings into measurable checks and engineering-rule concerns.
- `cad-reviewer`: compare repaired outputs against locked facts, parameter contract, and proceed gate.

If subagents are unavailable, the lead must run those roles sequentially and state that fallback explicitly.

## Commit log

2026-06-02 Initial Zen CAD v0.3.0 kit
    [bom.csv]
2026-06-02 Add one-command Zen CAD setup
    [bom.csv]
2026-06-02 Generalize Zen CAD quick start examples
2026-06-02 Add prompt-first Zen CAD milestone startup
2026-06-02 Bundle CAD companion skills and strengthen validation
2026-06-02 Simplify repository layout and localize README
    [bom.csv]
2026-06-02 Add first-run Zen CAD CLI
2026-06-02 Release Zen CAD 0.4.0 gate workflow
2026-06-02 Implement Zen CAD 0.5.0 generation-first workflow
    [bom.csv, nema17_mount_plate.step, nema17_mount_plate.stl]
2026-06-03 Release Zen CAD 0.6.1 harness adapter
2026-06-03 Release Zen CAD 0.6.2 evidence gates
2026-06-03 Release Zen CAD 0.6.3 skill contracts
2026-06-03 Release Zen CAD 0.6.4 companion skills
2026-06-03 Release Zen CAD 0.6.5 cobra cwd guidance
2026-06-03 Release Zen CAD 0.6.6 workspace root startup
2026-06-04 Update agentic-cad interface-first workflow
2026-06-04 Release Zen CAD 0.8 spec-first skills
2026-06-04 Reset to pure spec-first skill pack
    [bom.csv, nema17_mount_plate.step, nema17_mount_plate.stl]
2026-06-04 Deepen spec-first CAD generation loop
2026-06-04 README.md 업데이트
2026-06-04 Add CAD contract schemas and interface registry
2026-06-05 Bump Zen CAD version to 0.8.9
2026-06-05 Release Zen CAD 0.9.0 contract runner
2026-06-10 Release Zen CAD 1.0.0 contract handoff layer
2026-06-10 Import source-locked STEP parts into CAD source
2026-06-10 Package Zen CAD as installable Codex plugin
2026-06-10 Release Zen CAD 1.0.1
2026-06-11 Update CAD artifacts
    [bearing_608zz.step, compact_belt_drive_module_layout.step, iso4762_socket_head_cap_screw_m3x10.step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]
2026-06-11 Release Zen CAD 1.0.2
2026-06-11 Add CAD viewer workbench
    [generated-bracket.stl, simple-cube.step]
2026-06-11 Render STEP wireframes from BREP face edges
2026-06-11 Include CSG boundaries in viewer wireframes
2026-06-11 Release Zen CAD 1.1.0 replacement workflows

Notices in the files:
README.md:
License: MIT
